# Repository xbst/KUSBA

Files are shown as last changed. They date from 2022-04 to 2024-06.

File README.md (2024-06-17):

# Klipper USB Accelerometer
A PCB designed to make [Klipper's](https://github.com/KevinOConnor/klipper) [input shaping](https://github.com/Klipper3d/klipper/blob/master/docs/Resonance_Compensation.md) much easier by simplifying the wiring and config for [measuring resonances](https://github.com/KevinOConnor/klipper/blob/master/docs/Measuring_Resonances.md). You just need this PCB and a USB C cable.
<br>

## Purchasing a KUSBA
### United States
- [Amazon - Prime Shipping](https://www.amazon.com/Isiks-Tech-KUSBA-Klipper-Accelerometer/dp/B0C734JL4Z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)
- [Isik's Tech Store](https://store.isiks.tech/products/kusba-klipper-usb-accelerometer) (Me)
- [West3D](https://west3d.com/products/kusba-klipper-usb-accelerometer-by-isikstech)
- [XR Bunker](https://xrbunker.works/products/kusba-by-xbst_isik)
### Canada
- [Amazon - Ships from the US](https://www.amazon.ca/dp/B0C734JL4Z)
### United Kingdom
- [Printy Please](https://www.printyplease.uk/KUSBA)
### European Union
- [Lab4450 - Portugal](https://lab4450.com/product/ksuba-adxl345/)
### Australia
- [Unique Prints](https://uniqueprints.shop/shop/electronics-electrical/pcb/kusba-usb-adxl345-accelerometer-for-klipper/)
- [DREMC](https://store.dremc.com.au/products/kusba-usb-adxl345-accelerometer-for-klipper)
- [Orvil3D](https://orvil3d.com/products/kusba)

This project is licensed under [GPL v3](./LICENSE), meaning vendors are allowed to sell KUSBA PCBs without paying me. If you'd like to support the development of this and future projects please consider [sponsoring](https://github.com/sponsors/xbst) me on GitHub. You can also subscribe on [Patreon](https://l.isiks.tech/patreon) or [YouTube](https://l.isiks.tech/member).

You can also use the included gerber files to order your own from a PCB manufacturer like [PCBWay](https://www.pcbway.com/setinvite.aspx?inviteid=374841) or [JLCPCB](https://jlcpcb.com/).
<br>

## Instructions
[KUSBA Instructions](./Docs/v2-Rampon-Firmware.md)

## Toolhead Mounts

Toolhead mounts can be found [here](./Mounts).
<br>The CAD model of the PCB and some toolhead mounts can be found [here](./CAD).
<br> 

## Versions

| Parts | KUSBA v2 | KUSBA v1 |
| --- | --- | ---|
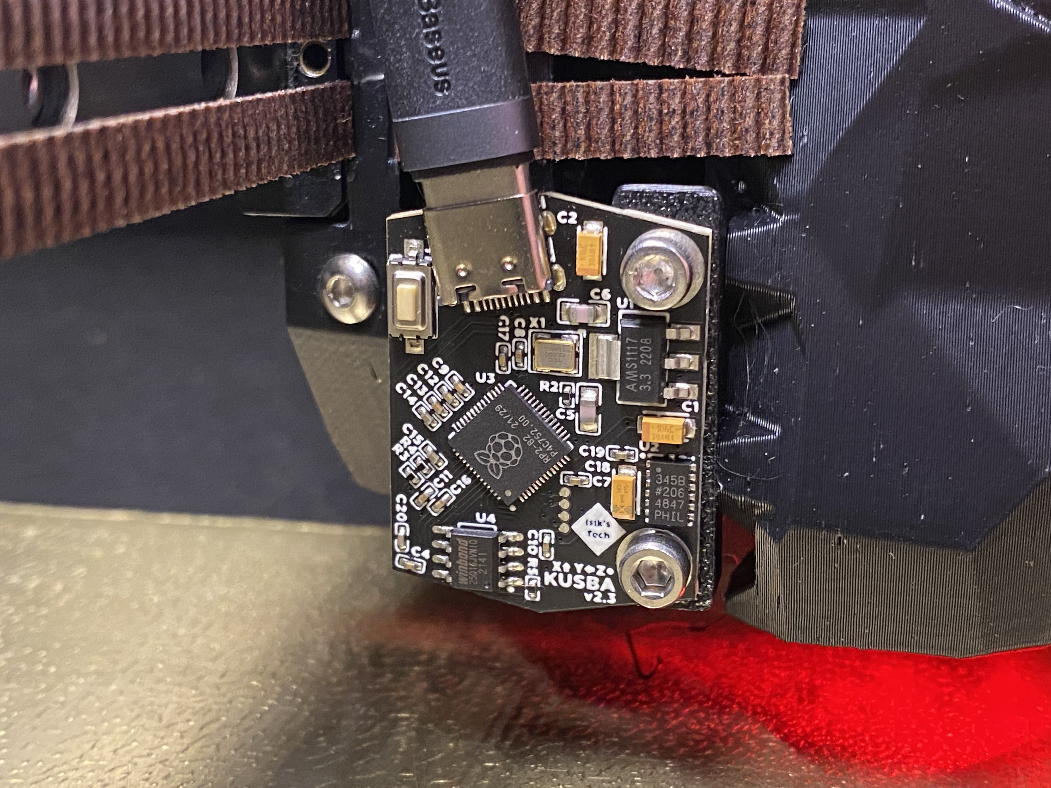
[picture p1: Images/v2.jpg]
v2.3
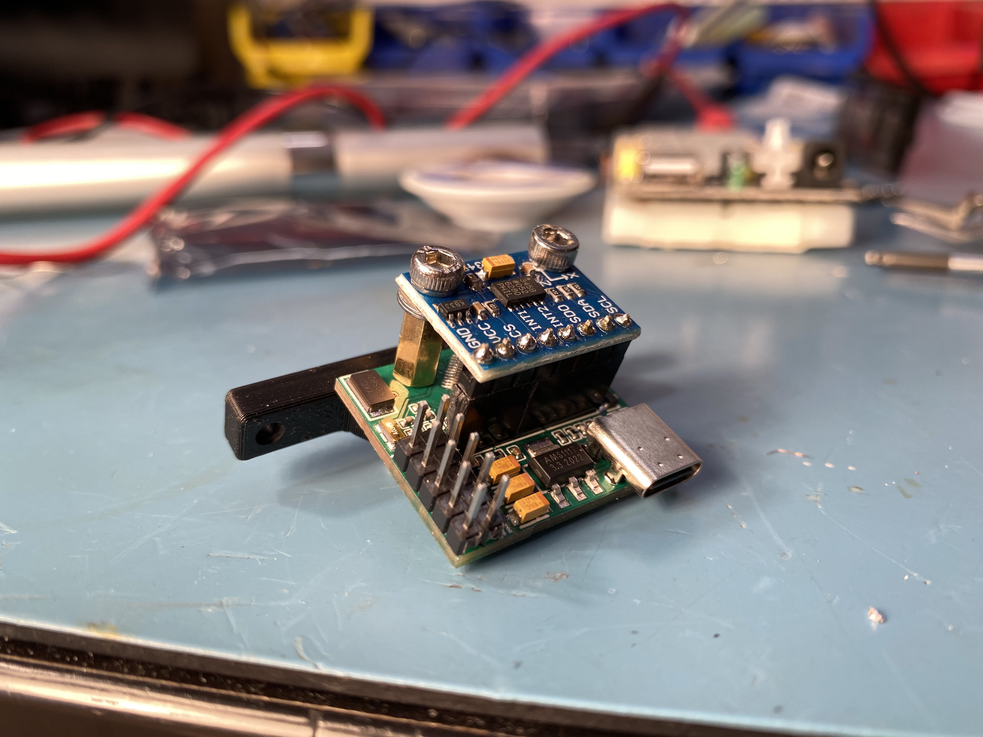
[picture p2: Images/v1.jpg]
v1.0
| Picture |  |  |
| YouTube Video | [YouTube Video](https://www.youtube.com/watch?v=gtrQXdAaXB4) | [YouTube Video](https://www.youtube.com/watch?v=tDQd-jGegX0) |
| MCU | RP2040 | STM32F103 |
| Accelerometer | ADXL345BCCZ-RL7 | External ADXL345 Module |
| 3.3V Regulator | AMS1117-3.3 | AMS1117-3.3 |
| Flash | W25Q16JVSNIQ | N/A |
| Connector | USB C | [USB C](https://www.digikey.com/en/products/detail/gct/USB4085-GF-A/9859733) |
| Smallest SMT | 0402 | 0402 |
| Other Parts Needed | USB C Cable, M3 Screws | ADXL345 Module, USB C Cable, M3 Screws, UART Programmer |
| Dimensions | 34.0 x 25.0 mm | 25.0 x 30.0 mm |

TL;DR: v2 is better

## YouTube

I am a YouTube content creator. If you want content about these projects & more, please consider [subscribing to my YouTube channel](https://www.youtube.com/channel/UClAWYmCkHjsbaX9Wz1df2mg).
<br>

If you feel like contributing to the development of this project and other projects like this you can sponsor me on [GitHub](https://github.com/sponsors/xbst), subscribe on [Patreon](https://l.isiks.tech/patreon) or [YouTube](https://l.isiks.tech/member).

## Notes
- Readme files in this repo contain Amazon Associate, Aliexpress affiliate, PCBWay affiliate links. I make a comission on qualifying purchases.
- This project does not come with any warranty, if you choose to build/use a KUSBA, you are doing this at your own risk!
- If you want to sell KUSBA PCBs, you are allowed to, and you will not owe me any royalties. **You cannot claim that I endorse the sale**. You can check the license file for more information. However, if you **wish** to give me a share you can sponsor me on [GitHub](https://github.com/sponsors/xbst), subscribe on [Patreon](https://l.isiks.tech/patreon) or [YouTube](https://l.isiks.tech/member).

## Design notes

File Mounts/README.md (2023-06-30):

# Mounts
|Name|Toolhead|KUSBA Version|Notes|By|
|---|---|---|---|---|
|[StealthBurner Mount](./StealthBurner.stl)|Voron StealthBurner|v2.3 & v2.4|Limits X travel very slightly (negligible)|xbst_|
|[StealthBurner Cover](./SB_cover.stl)|Voron StealthBurner|v2.3 & v2.4|Optional cover, further limits X travel but only a few mm|Samwiseg0|
|[AfterBurner Mount](./AfterBurner.stl)|Voron AfterBurner|v2.3 & v2.4|UNTESTED but should work. Front mount.|xbst_|
|[Mini-SB Front Mount](./MiniSB_Front.stl)|Voron Mini-StealthBurner|v2.3 & v2.4|Easiest mount to attach/remove. Very similar to the Mini-AB mount|xbst_|
|[Mini-SB Rear Mount](./MiniSB_Patrick.stl)|Voron Mini-StealthBurner|v2.3 & v2.4|If you prefer accelerometers near the carriage use this one. Alternate strain relief with the KUSBA mount. Not compatible with toolhead PCBs|xbst_|
|[Mini-AB Front Mount](./MiniAB.stl)|Voron Mini-AfterBurner|v2.3 & v2.4|Mounts the KUSBA in front of the toolhead, replace the 2 long M3 screws|xbst_|
|[Mini-AB Cover](./MiniAB_Cover.stl)|Voron Mini-AfterBurner|v2.3 & v2.4|Optional cover|Samwiseg0|
|[M6 KUSBA Nozzle Mount](./M6_KUSBA_Mount.stl)|M6 Nozzle Mount|v2.3 & v2.4|Cover recommended so Tap homing can be used. Requires M6 SHCS/BHCS 10mm screw, remove nozzle. Add "axes_map: y, x, z" to [adxl345] section config for proper orientation with the USB-C facing forward. |GiulianoM|
|[Dragon Burner Mount](./Dragon_Burner_Rigonzalez6.stl)|Dragon Burner|v2.3 & v2.4||rigonzalez6|
|[MicroSwiss NG Mount](./MicroSwiss_NG.stl)|MicroSwiss NG Direct Drive|v2.3 & v2.4|It uses inserted M3 nuts to mount the KUSBA board and fix it to the extruder backplate. [Print details](https://www.printables.com/model/516393-kusba-mount-for-micro-swiss-ng-extruder) |luisillo26|

<br>**Feel free to contribute more mounts. Either create a PR or DM me on Discord to contribute.**
<br>**KUSBA v1.0 users can use the standard ADXL345 mounts. The mount holes are the same as the GY ADXL345 module, size might be a problem.**

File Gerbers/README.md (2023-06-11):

# HW Changelog

|Version|Notes|Files|
|---|---|---|
|v1.0|Read the main [Readme](../README.md#version-10) file for more information.|[Gerbers](./Old-Versions/v1.0)|
|v2.0|More info about v2 vs v1 is on the main [Readme](../README.md).|Not Released (HW Bugs)|
|v2.1| Fixed the v2.0 communication problems.|Not Released (HW Bugs)|
||Many components are relocated.||
||LED is removed because it was unnecessary.||
||PCB is smaller now (35.6mmx25mm).||
|v2.2|Made the PCB slightly larger (36.4mmx25mm) to allow the use of M3 screws. |Not Released (Untested)|
||Made some test pads larger.||
|v2.3|Fixed a HW bug that affects about 20% of PCBs (or less based on another person ordering v2.1).|[Gerbers](./Old-Versions/v2.3)|
||PCB is even smaller (34mmx25mm) while still using M3 screws.||
|v2.4|Adds USB C-to-C cable support.|[Gerbers](./Latest-Tested-Version)|
||Minor silkscreen and other cosmetic changes.||
||Same size and layout. Compatible with v2.3 mounts.||

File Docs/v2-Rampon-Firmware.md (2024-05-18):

### 0. Klipper Prep
Taken from the [official Klipper docs](https://www.klipper3d.org/Measuring_Resonances.html#software-installation).
1. Run the following commands in order. This will take some time.
```
~/klippy-env/bin/pip install -v numpy
sudo apt update
sudo apt install python3-numpy python3-matplotlib libatlas-base-dev libopenblas-dev
```

### :warning: Seeing "MCU Protocol Error"?
Klipper devs did some major changes to the ADXL code, and as a result older Rampon is not compatible with newer Klipper versions, and vice-versa.
If your Klipper version is v0.12.0-85 or later, use Rampon v0.4. If it is before this update, use Rampon v0.3. If your KUSBA stopped working after a Klipper update, you need v0.4.

|Klipper Pre-"Bulk Sensor" Update|Klipper Post-"Bulk Sensor" Update|
|---|---|
|[v0.3](https://github.com/rogerlz/rampon_anchor/releases/download/v0.3.0/rampon_anchor_kusba.uf2)|[v0.4](https://github.com/rogerlz/rampon_anchor/releases/download/v0.4.0/rampon_anchor_kusba.uf2)|

Follow these steps to flash firmware:

### 1. Flash Rampon Anchor to the MCU

You can do this step on a PC or on your Raspberry Pi (or another Linux machine).
<br> Your KUSBA might already have the firmware pre-flashed. If it does, you can skip this step.
<details>
  <summary>PC (Easier)</summary>

1. Download the Rampon Anchor Firmware from its [GitHub repo](https://github.com/rogerlz/rampon_anchor).

|Klipper Pre-"Bulk Sensor" Update|Klipper Post-"Bulk Sensor" Update|
|---|---|
|[v0.3](https://github.com/rogerlz/rampon_anchor/releases/download/v0.3.0/rampon_anchor_kusba.uf2)|[v0.4](https://github.com/rogerlz/rampon_anchor/releases/download/v0.4.0/rampon_anchor_kusba.uf2)|

2. Connect the KUSBA to your PC while holding down the button on the KUSBA. A new drive will be connected, open if it isn't opened automatically.
3. Drag & drop the downloaded .UF2 file. KUSBA will disconnect and the window will close on its own. Your KUSBA is ready.
</details>
<details>
  <summary>Raspberry Pi (Linux CLI)</summary>

  1. Connect the KUSBA to your Raspbery Pi while holding down the button on the KUSBA.
  2. SSH into your Raspberry Pi.
  3. Download the Rampon Anchor Firmware from its [GitHub repo](https://github.com/rogerlz/rampon_anchor).
  ```
  sudo wget https://github.com/rogerlz/rampon_anchor/releases/download/v0.4.0/rampon_anchor_kusba.uf2
  ```
  4. Find the storage location of the KUSBA. This will usually be sda1. Use this command one time with the KUSBA unplugged and one time with KUSBA plugged in (while holding down the button on the KUSBA) to verify. `ls /dev/`
  5. Flash the firmware.
  ```
  sudo mount /dev/sda1 /mnt
  sudo cp rampon_anchor_kusba.uf2 /mnt
  sudo umount /mnt
  ```
</details>

### 2. Configure Klipper
1. Download the [adxlmcu.cfg](../Firmware/v2-Rampon/adxlmcu.cfg) file from this repo and add it to your Klipper config directory.
4. Edit the adxlmcu.cfg file. Change the the probe points.
5. Add the following to your printer.cfg:
```
[include adxlmcu.cfg]
```
4. Do your testing. When done comment the include line to disable the KUSBA. (If you don't do this and unplug the KUSBA, Klipper won't work.)
```
# [include adxlmcu.cfg]
```

<details>
  <summary>LEGACY INSTRUCTIONS</summary>
  
  Ignore unless you know you need these instructions.
  
  [KUSBA v2 Non-Rampon Klipper Instructions](./v2-Firmware.md) - NOT RECOMMENDED
  
  [KUSBA v1 Instructions](./v1-Firmware.md)
  
</details>

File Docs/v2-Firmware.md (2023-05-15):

### 0. Klipper Prep
Taken from the [official Klipper docs](https://www.klipper3d.org/Measuring_Resonances.html#software-installation).
1. Run the following commands in order. This will take some time.
```
~/klippy-env/bin/pip install -v numpy
sudo apt update
sudo apt install python3-numpy python3-matplotlib libatlas-base-dev
```

### 1. Flash Klipper to the MCU
1. Connect the KUSBA to your Raspbery Pi while holding down the button on the KUSBA.
2. SSH into your Raspberry Pi.
3. Go to the Klipper directory
```
cd klipper
```
4. Clean remaining files from previous build.
```
make clean
```
5. Choose the options for the build.
```
make menuconfig
```
Use the following settings:
```
Micro-controller Architecture: Raspberry Pi RP2040
Communication inferface: USB
```
6. Build the firmware
```
make
```
7. Find the storage location of the KUSBA. This will usually be sda1. Use this command one time with the KUSBA unplugged and one time with KUSBA plugged in (while holding down the button on the KUSBA) to verify.
```
ls /dev/
```
8. Flash the firmware.
```
sudo mount /dev/sda1 /mnt
sudo cp out/klipper.uf2 /mnt
sudo umount /mnt
```

### 2. Configure Klipper
1. Go back to the home directory.
```
cd ~
```
2. Download the [adxlmcu.cfg](../Firmware/v2/adxlmcu.cfg) file from this repo and add it to your Klipper config directory.
3. Find your MCU address.
```
ls /dev/serial/by-id/*
```
4. Edit the adxlmcu.cfg file. Change the MCU serial address and the probe points.
5. Add the following to your printer.cfg:
```
[include adxlmcu.cfg]
```
6. Do your testing. When done comment the include line to disable the KUSBA. (If you don't do this and unplug the KUSBA, Klipper won't work.)
```
# [include adxlmcu.cfg]
```

<br>

### NOTE: The first reading from the accelerometer will be invalid (usually f2 vs e5). This is expected and your KUSBA will still work fine after the first query. Run ``ACCELEROMETER_QUERY`` once before starting measuring resonances.

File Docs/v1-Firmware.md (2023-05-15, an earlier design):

**Warning: Make sure to use plastic washers between metal screws and PCB!**

### 0. Klipper Prep
Taken from the [official Klipper docs](https://www.klipper3d.org/Measuring_Resonances.html#software-installation).
1. Run the following commands in order. This will take some time.
```
~/klippy-env/bin/pip install -v numpy
sudo apt update
sudo apt install python3-numpy python3-matplotlib libatlas-base-dev
```
### 1. Flash the Bootloader
You will need a USB UART programmer. I recommend using a CP2012 programmer, because it is cheap, easy to source, and it works.
Programmer:
[Aliexpress](https://s.click.aliexpress.com/e/_AB7gkA)
[Amazon](https://amzn.to/2OTzpI8)

You will also need some Female/Female dupont cables:
[Aliexpress](https://s.click.aliexpress.com/e/_9GgrhS)
[Amazon](https://amzn.to/3uAZU5E)

1. Download & install the [CP2012 drivers](https://www.silabs.com/developers/usb-to-uart-bridge-vcp-drivers). (on your Windows PC)
2. Download & install the [flasher](https://www.st.com/en/development-tools/flasher-stm32.html). (on your Windows PC)
3. Download the [STM32duino bootloader](https://github.com/rogerclarkmelbourne/STM32duino-bootloader/blob/master/binaries/maple_mini_boot20.bin). (on your Windows PC)
4. Jump the boot pins:
<br>BOOT0 > VCC
<br>BOOT1 > GND
5. Connect power from UART programmer:
<br>3V3 > VCC
<br>GND > GND
6. Connect the UART pins:
<br>TX > RX1
<br>RX > TX1
7. Plug in the UART programmer to your Windows PC.
8. Launch the Demonstratior GUI (STM32 Flasher Software).
9. Choose the correct COM port, hit next, and next again.
10. Make sure the chip detected in this step is correct, hit next again.
11. Choose "Download to device", click "..." to select the bin file. You will need to change the file type from .s19 to .bin in the dialog. Check "Verify after download", and hit next.
12. The bootloader will now be flashed. One it is complete you can exit the program. Unplug the programmer, and remove all wires and jumpers from the PCB.

### 2. Flash Klipper to the MCU
1. Connect the KUSBA to your Raspbery Pi. The LED on the PCB should be flashing.
2. SSH into your Raspberry Pi.
3. Go to the Klipper directory
```
cd klipper
```
4. Clean remaining files from previous build.
```
make clean
```
5. Choose the options for the build.
```
make menuconfig
```
Use the following settings:
```
Micro-controller Architecture: STMicroelectronics STM32
Processor Model: STM32F103
Bootloader Offset: 8KiB Bootloader (stm32duino)
```
6. Build the firmware
```
make
```
7. Verify that the MCU is connected. There should be a "1eaf:0003" device connected. 
```
lsusb
```
If there is no "1eaf:0003" but there is a "1eaf:0004":
<br>
Sometimes the bootloader runs for only a short period after boot (if it thinks there is already a program, so it boots to it). If you unplug & replug in the mcu, and run the "lsusb" quickly enough, you will see a "1eaf:0003". If this is the case, you will need to time the next step well.

8. Flash the firmware.
```
dfu-util -d 1eaf:0003 -a 2 -R -D out/klipper.bin
```
9. Reset or unplug and replug in the MCU.

### 3. Configure Klipper
1. Go back to the home directory.
```
cd ~
```
2. Download the [adxlmcu.cfg](../Firmware/v1/adxlmcu.cfg) file from this repo and add it to your Klipper config directory.
3. Find your MCU address.
```
ls /dev/serial/by-id/*
```
4. Edit the adxlmcu.cfg file. Change the MCU serial address and the probe points.
5. Add the following to your printer.cfg:
```
[include adxlmcu.cfg]
```
6. Do your testing. When done comment the include line to disable the KUSBA. (If you don't do this and unplug the KUSBA, Klipper won't work.)
```
# [include adxlmcu.cfg]
```

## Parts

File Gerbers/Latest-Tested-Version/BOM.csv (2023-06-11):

ID | Name | Designator | Footprint | Quantity | Manufacturer Part | Manufacturer | Supplier | Supplier Part | Price
1 | 12MHz | X1 | OSC-SMD_4P-L3.2-W2.5-BL | 1 | X322512MSB4SI | YXC | LCSC | C9002 | 0.014
2 | USB3.1C16PFSMT | USBC2 | USB-C-SMD_TYPE-C-USB-17 | 1 | - | LCSC | LCSC | C167321 | 0.059
3 | RP2040 | U3 | LQFN-56_L7.0-W7.0-P0.4-EP | 1 | RP2040 | Raspberry Pi(树莓派) | LCSC | C2040 | 0.174
4 | ADXL345BCCZ-RL7 | U2 | LGA-14_L5.0-W3.0-P0.80-BL | 1 | ADXL345BCCZ-RL7 | ADI | LCSC | C9667 | 0.269
5 | AMS1117-3.3 | U1 | SOT-223-3_L6.5-W3.4-P2.30-LS7.0-BR | 1 | AMS1117-3.3 | AMS | LCSC | C6186 | 0.024
6 | K2-3.6×6.1_SMD | BOOTSEL1 | KEY-SMD_2P-L6.2-W3.6-LS8.0 | 1 | K2-1107ST-A4SW-06 |  | LCSC | C118141 | 0.011
7 | 10u | C1,C3 | CAP-SMD_L3.2-W1.6-R-RD | 2 | TAJA106K016RNJ | AVX | LCSC | C7171 | 0.014
8 | 1u | C18 | CAP-SMD_L3.2-W1.6-R-RD | 1 |  |  | LCSC | C141744 | 0.011
9 | W25Q16JVSNIQ | U4 | SOIC-8_L4.9-W3.9-P1.27-LS6.0-BL | 1 | W25Q16JVSNIQ | Winbond Elec | LCSC | C115407 | 0.062
10 | 1K 1% | R5 | R0402 | 1 |  |  | LCSC | C11702
11 | 27R4 1% | R4,R3 | R0402 | 2 |  |  | LCSC | C31439
12 | 2u2 | C20 | C0402 | 1 |  |  | LCSC | C12530
13 | 100n | C17,C16,C13,C12,C11,C10,C9,C8,C7,C4,C19 | C0402 | 11 |  |  | LCSC | C1525
14 | 1u | C15,C14 | C0402 | 2 |  |  | LCSC | C52923 | 0.001
15 | 470R 1% | R2 | R0402 | 1 |  |  | LCSC | C25117
16 | 27p | C6,C5 | C0603 | 2 |  |  | LCSC | C107045
17 | 5K1 1% | R6,R7 | R0402 | 2 |  |  | LCSC | C328327 | 0.001

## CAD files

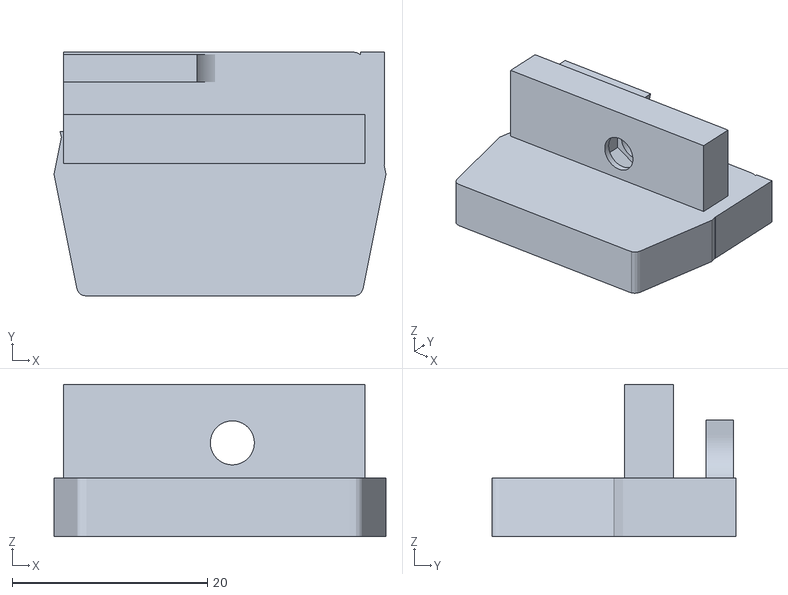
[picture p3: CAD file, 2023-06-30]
Mounts/MicroSwiss_NG.stl
34.0 x 25.0 x 15.6

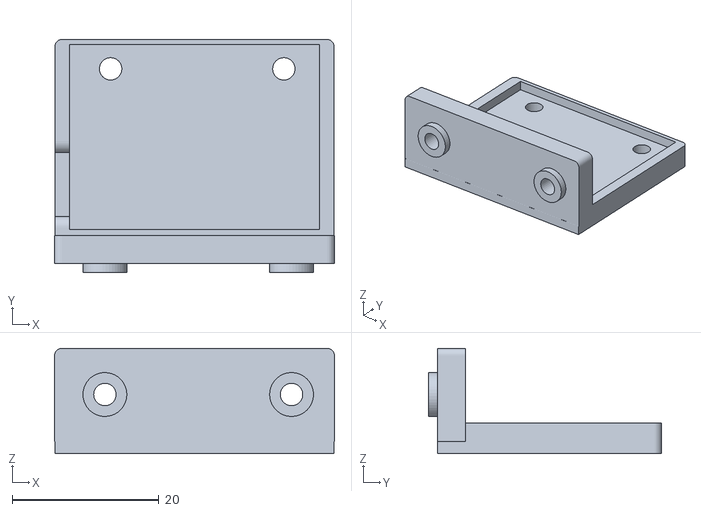
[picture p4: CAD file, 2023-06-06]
Mounts/Dragon_Burner_Rigonzalez6.stl
38.1 x 31.8 x 14.3

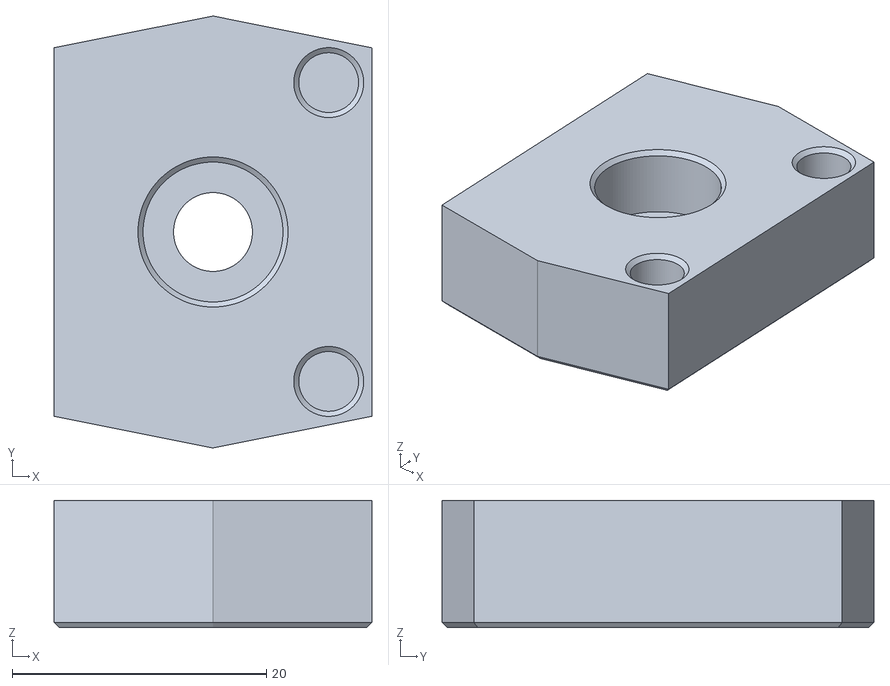
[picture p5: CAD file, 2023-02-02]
Mounts/M6_KUSBA_Mount.stl
25.0 x 34.0 x 10.0

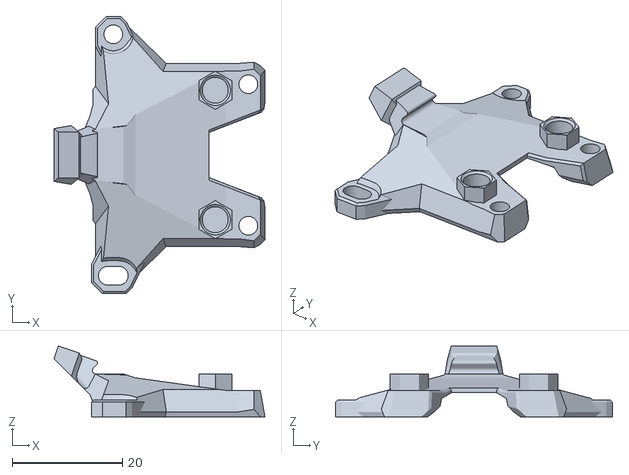
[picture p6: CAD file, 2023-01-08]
Mounts/MiniSB_Patrick.stl
38.3 x 50.3 x 12.9

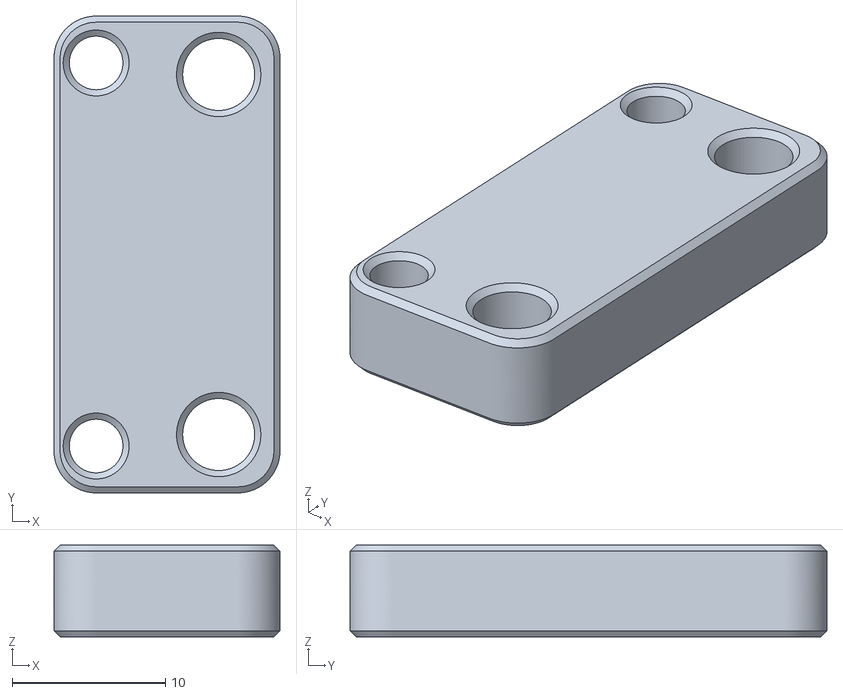
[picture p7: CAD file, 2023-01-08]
Mounts/MiniSB_Front.stl
14.8 x 31.1 x 6.00

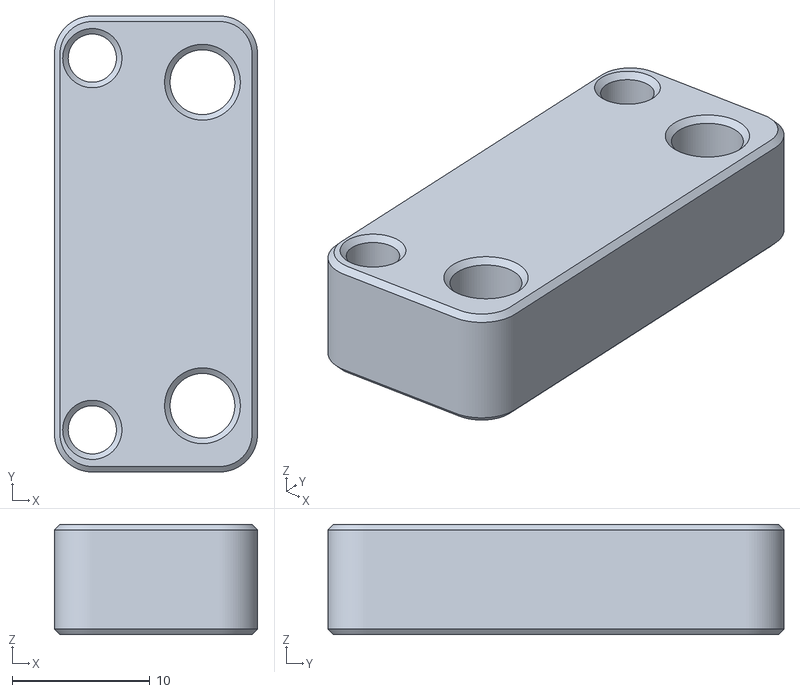
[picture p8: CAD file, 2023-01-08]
Mounts/MiniAB.stl
14.8 x 33.1 x 8.00

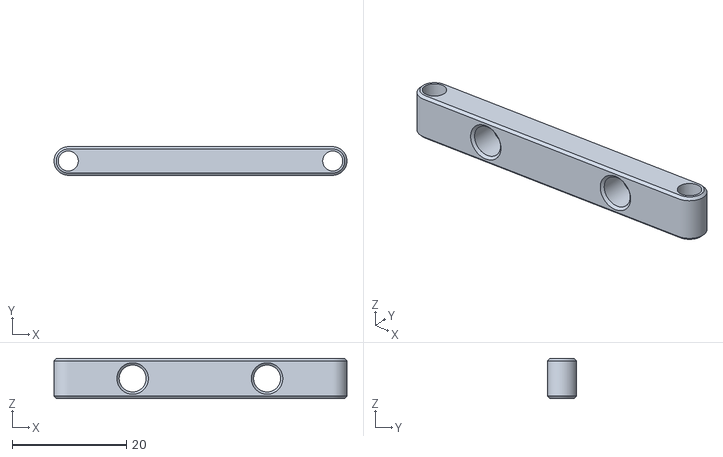
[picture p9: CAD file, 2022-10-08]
Mounts/AfterBurner.stl
51.2 x 5.00 x 7.00

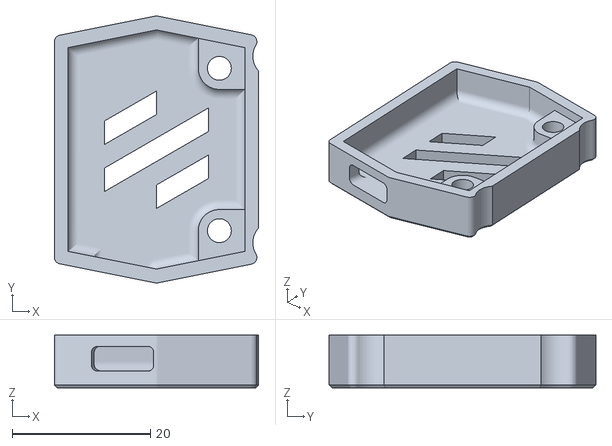
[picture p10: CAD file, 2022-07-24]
Mounts/MiniAB_Cover.stl
29.6 x 38.7 x 7.60

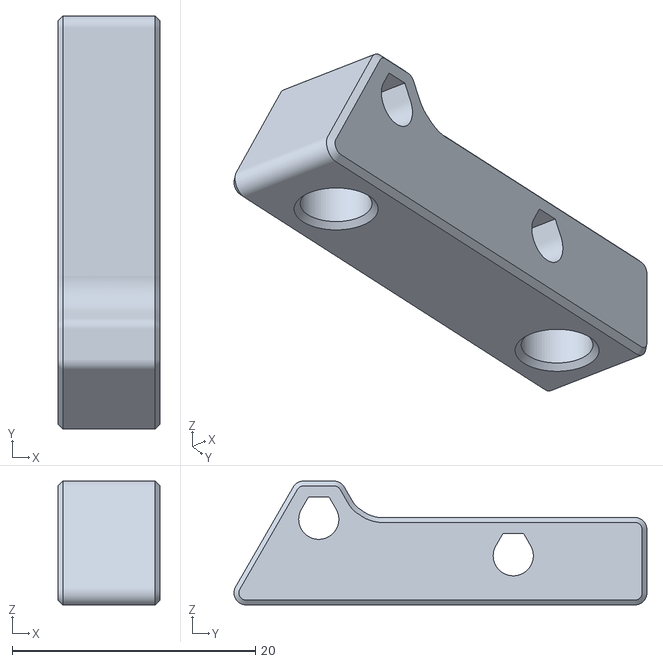
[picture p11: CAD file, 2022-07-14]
Mounts/StealthBurner.stl
8.40 x 34.0 x 10.2

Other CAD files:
Mounts/SB_cover.stl

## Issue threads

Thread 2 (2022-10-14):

Perhaps dumb question - will this work with a laptop running Ubuntu?

wiilover22, 2022-10-14:
This is probably a really stupid question - but since RPI's are so scarce right now, I'm running Klipper on an old laptop of mine sitting next to my 3D printer.

Which is why I went looking for USB connection ADXL345's.

If I already have Klipper installed on the Laptop, and my 3D printer flashed with the Klipper firmware - if I buy this USB ADXL345, is it just plug, config, and play? Does anything need to change? Thanks! Would love to buy one if it works with my laptop >.<

xbst, 2022-10-14:
It should work work fine, it's the same software. One thing to keep in mind is KUSBA is not compatible with USB C to C cables, so you need a USB A port on your laptop.

wiilover22, 2022-10-14:
So since I have everything installed already, it's just plug - setup the config file to read from the USB port - and run the resonance tests? Or do I have to recompile Klipper for my laptop or printer...or something?

Also...I have a bed slinger printer...does that mean I have to buy 2 of these so I can read the resonances from both the bed and printer head - if you happen to know...?

xbst, 2022-10-15:
You can just follow the instructions on this repo. I'm not sure where the wget command will download the cfg so you might have to manually move it. Other than that it should be the same.
You can buy just 1 and move the accelerometer, but if you want to measure both with 1 command or if you don't want to move it you will need 2.

wiilover22, 2022-10-15:
Thanks for the help!

Closed 2022-10-15.

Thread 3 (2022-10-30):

KUSBA with standard parts

Ritterbrater, 2022-10-30:
Hi,
nice project!
Instead of using a custom PCB I would like to take "standard" parts.
Is it possible to take a regular Raspberry Pi Pico Board with a ADXL345 module board? Do I only need to connect the pins GPIO0 - GPIO4 and then flash your firmware?

Another question: Are there any limitiations for the frequency measurement due to protocol change SPI <-> USB?

Thank you.

xbst, 2022-10-31:
It's possible. There are a few guides for that on the internet, I think Nero3D has a good video on that topic.

The protocol between the accelerometer and the MCU is still SPI, performance should be the same.

Ritterbrater, 2022-10-31:
Ah, ok, I see. E.g.: https://www.youtube.com/watch?v=W_VHbT_tsZw
Thank you for the explanations.

Closed 2022-10-31.

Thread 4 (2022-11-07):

documentation of the protocol

tcurdt, 2022-11-07:
Fantastic project.
I was thinking of building something similar for another context (non-Klipper).

I am trying to understand how the communication works over USB.
What's the protocol? Are there some docs?
Is the latency a problem for the measurements?

Where is the code that actually runs on the MCU?
And what's the flash used for?

xbst, 2022-11-07:
The protocol is spi to the rp2040, then usb, so no different from the normal klipper setup. Latency shouldn't be any different compared to wiring the spi pins to a normal controller or a pi pico. The code is klipper, built at the time of flashing with the latest files available at the time.  flash is used to store the klipper code.

tcurdt, 2022-11-07:
> The protocol is spi to the rp2040

of course

> then usb

And that's the bit I am after.
But it sounds like this might be more of a question for the Klipper project.

To give more context:
Let's say I connect board and connect it to linux machine.
How could I talk to the board (without using Klipper)?

Seems I would need a custom firmware for the rp2040 and something on the host as well.

xbst, 2022-11-08:
Probably something can be programmed for that with arduino IDE.

Closed 2022-11-12.

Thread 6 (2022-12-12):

`Invalid adxl345 id (got f2 vs e5)` error running `ACCELEROMETER_QUERY` for the first time

hakimio, 2022-12-12:
I understand that `Invalid adxl345 id (got f2 vs e5)` error is documented but instead of ignoring it, it should be fixed. This doesn't happen with `FYSETC Portable Input Shaper` and should not happen with `KUSBA`.

xbst, 2022-12-13:
This happens with a Raspberry Pi Pico with ADXL345 too, not just KUSBA. This is a Klipper problem and there is nothing I can do to fix it.

hakimio, 2022-12-13:
- Why doesn't this happen with `FYSETC Portable Input Shaper` which also uses `RP2040`?
- If it's Klipper bug, where is the bug report and, if you know what's causing the issue, why don't you create a PR for Klipper?

hakimio, 2022-12-13:
I guess you were referring to this closed bug report: https://github.com/Klipper3d/klipper/issues/4712

xbst, 2022-12-13:
I have no idea why FYSETC PIS doesn't have this problem. Me and other people (simple discord searches can find some recent examples) had the invalid ID issue on the first query with Pi Picos too, not just KUSBA. This indicates a software issue.

One difference between the KUSBA vs PIS is, PIS uses different GPIO pins for the SPI bus to the ADXL, could be related. But the pins the KUSBA use are full HW SPI pins too, and they should work the same. Again, the only possible explanation I can think of for this is a Klipper bug, even if it is not reported on GitHub.

hakimio, 2022-12-13:
Can you create a bug report on Klipper repo and link it here?

Fragmon, 2023-01-04:
Hey, i try to create a macro that use the query for the test. But klipper dont stop the execution between the macros. Do you know a solution?

   ACCELEROMETER_QUERY
   G4 P10000
   TEST_RESONANCES AXIS=X

Fragmon, 2023-01-04:
I found a solution:

Use this:
[adxl345]
cs_pin: adxl:gpio1
#spi_bus: spi0a
spi_software_sclk_pin: adxl:gpio2
spi_software_mosi_pin: adxl:gpio3
spi_software_miso_pin: adxl:gpio0

xbst, 2023-01-12:
Ideally I prefer hardware SPI over software SPI, but I'll test it and if this fixes the issue without producing worse results I'll add it as an option to the .cfg.

Witawat, 2023-02-24:
Invalid adxl345 id (got f2 vs e5).
This is generally indicative of connection problems
(e.g. faulty wiring) or a faulty adxl345 chip.

how to fix ?
or use klipper version ?

xbst, 2023-02-24:
It is covered in the instructions: https://github.com/xbst/KUSBA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
First reading will be invalid, should work fine after that.

Closed 2023-02-02.

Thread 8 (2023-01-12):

Issues reconnecting the MCU

housam-s, 2023-01-12:
After setting up the KASUBA ADXL and following the steps below, i got it to work perfectly the first time.
However, upon unplugging it and putting it away for a while, I wasnt able to get it going again easily. I am finding myself having to run through all the steps again before it will randomly decide to show up as an MCU USB device.
Seems like a bit of work to get it going again after unplugging it. Is this the way it is supposed to be or am I missing something?

EDIT: User error, have additional USB devices plugged in which have changed the port ID they are connected to.

Closed 2023-01-12.

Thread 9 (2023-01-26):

Unknown spi_bus 'spi0a'

mmithoefer, 2023-01-26:
I flashed my KUSBA and adjusted my serial address to : `serial: /dev/serial/by-id/usb-Klipper_rp2040_E661347507974224-if00` which i determined by using `ls /dev/serial/by-id/*`.
When i try to start klipper i get  the following error:

`Unknown spi_bus 'spi0a'`

when I uncomment the [include adxlmcu.cfg] and add
```
[mcu adxl]
serial: /dev/serial/by-id/usb-Klipper_rp2040_E661347507974224-if00
```
to my printer.cfg it starts just fine and the mcu adxl shows up in mainsail on the config tab

xbst, 2023-01-29:
You don't add the mcu to the printer.cfg, the mcu is in the adxlmcu.cfg. You just need to change the address in that file.

mmithoefer, 2023-01-29:
I´m aware of that. I did that only as a trouble-shooting measure. Whenever
 `[adxl345]
cs_pin: adxl:gpio1
spi_bus: spi0a`
is uncommented i get the described error

xbst, 2023-01-30:
That is weird. Can you update klipper? It sounds like a software issue since spi0a is a bus defined in the Klipper code for the RP2040.

mmithoefer, 2023-01-30:
I just did. Same error unfortunately

xbst, 2023-02-01:
Can you attach your printer.cfg and all .cfg files included with [include]?

mmithoefer, 2023-02-01:
Found the problem. Mistake on my part. I had a adxl section in my printer.cfg from previous experiments with other accelerometers.

Closed 2023-02-01.

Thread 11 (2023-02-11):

2.3 board loses flash if disconnected

cyborgcnc, 2023-02-11:
I have a 2.3 board, and it works as it should when flashed, however, if I disconnect the board, the flash file is no longer there....I have to go through the steps of mounting the file system again, and re-flashing, and then it works again...I thought this was supposed to be fixed in 2.3, but I am finding it is still there....wondering if I am doing something wrong?  Accelerometer works as it should once flashed, Klipper sees it etc.

xbst, 2023-02-11:
This is a known issue even with v2.3 but only affects about 1-2% of the PCBs according to data I get from vendors. Most of these are caught by the vendor before shipping to the customer but sometimes a faulty one is accidentally shipped. It sounds like you might have one of these PCBs unfortunately. Try contacting the seller.

cyborgcnc, 2023-02-11:
OK, I will do that...in the mean time, I guess I will keep re-flashing it for when I want to use it....royal  pain in the you know what....Thanks for your response!

pellcorp, 2023-11-09:
I have this exact issue with the 2.4 board as well :-(

Closed 2023-02-11.

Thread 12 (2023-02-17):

Trouble with make menuconfig

jperquin, 2023-02-17:
Have Fluiddpi / Moonraker Klipper installed on a Rpi 3b (BCM2835) and has been running fine with my Creality Ender6 that has been Klipper-ized with a custom flavour (https://3dprintbeginner.com/how-to-install-klipper-on-creality-ender-6/)

The KUSBA 2.3 is supposed to come pre-flashed with Klipper but does not show up under ls /dev/serial/by-id/*. The Ender6 does however (/dev/serial/by-id/usb-1a86_USB_Serial-if00-port0).

So figured I need to (re)flash the KUSBA, but following the instructions, I am running into an issue with make menuconfig.

I am supposed to be able to select these options:
```
Micro-controller Architecture: Raspberry Pi RP2040
Communication inferface: USB
```
But I am getting this of options for Micro-controller Architecture:

```
( ) Atmega AVR
( ) SAM3/SAM4 (Due and Duet)
( ) SAMD21/SAMD51
( ) LPC176x (Smoothieboard)
( ) STMicroelectronics STM32
( ) Beaglebone PRU
(X) Linux process
( ) Host simulator
```
So no "Raspberry Pi RP2040"..

Not sure how to proceed..

Your help is much appreciated.
Rgds, JP

xbst, 2023-02-17:
When did you last update Klipper? RP2040 is a newer chip than those so you might be running a really outdated version, from before RP2040 support. Try updating Klipper.

xbst, 2023-03-02:
Solved in another issue.

Closed 2023-03-02.

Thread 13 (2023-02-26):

KUSBA not recognized on USB

DK4FT, 2023-02-26:
received my KUSBA from lab4450.com a while ago and try to include it in my system now without success.

When pluggin in(with button pressed) the device is not recognized as a drive on my RPi.
As lab4450 mention on their page, that their devices are pre-flashed with the klipper firmware I tested also without button pressed, but the KUSBA is not regognized.

Here snippets from the syslog on the klipper machine..

1. KUSBA just pluggged in:
```
Feb 26 09:19:06 klipper kernel: [321786.579968] usb 1-1.3: new full-speed USB device number 7 using xhci_hcd
Feb 26 09:19:07 klipper kernel: [321786.680213] usb 1-1.3: device descriptor read/64, error -32
Feb 26 09:19:07 klipper kernel: [321786.900097] usb 1-1.3: device descriptor read/64, error -32
Feb 26 09:19:07 klipper kernel: [321787.020502] usb 1-1-port3: attempt power cycle
Feb 26 09:19:08 klipper kernel: [321787.679929] usb 1-1.3: new full-speed USB device number 8 using xhci_hcd
Feb 26 09:19:08 klipper kernel: [321787.680199] usb 1-1.3: Device not responding to setup address.
Feb 26 09:19:08 klipper kernel: [321787.900078] usb 1-1.3: Device not responding to setup address.
Feb 26 09:19:08 klipper kernel: [321788.119873] usb 1-1.3: device not accepting address 8, error -71
Feb 26 09:19:08 klipper kernel: [321788.219886] usb 1-1.3: new full-speed USB device number 9 using xhci_hcd
Feb 26 09:19:08 klipper kernel: [321788.220172] usb 1-1.3: Device not responding to setup address.
```

2. Button pressed while pluggin in:
```
Feb 26 09:29:39 klipper kernel: [322419.318065] usb 1-1.3: new full-speed USB device number 10 using xhci_hcd
Feb 26 09:29:39 klipper kernel: [322419.418291] usb 1-1.3: device descriptor read/64, error -32
Feb 26 09:29:40 klipper kernel: [322419.638243] usb 1-1.3: device descriptor read/64, error -32
Feb 26 09:29:40 klipper kernel: [322419.858042] usb 1-1.3: new full-speed USB device number 11 using xhci_hcd
Feb 26 09:29:40 klipper kernel: [322419.958247] usb 1-1.3: device descriptor read/64, error -32
Feb 26 09:29:40 klipper kernel: [322420.178245] usb 1-1.3: device descriptor read/64, error -32
Feb 26 09:29:40 klipper kernel: [322420.298645] usb 1-1-port3: attempt power cycle
Feb 26 09:29:41 klipper kernel: [322420.968050] usb 1-1.3: new full-speed USB device number 12 using xhci_hcd
Feb 26 09:29:41 klipper kernel: [322420.968288] usb 1-1.3: Device not responding to setup address.
Feb 26 09:29:41 klipper kernel: [322421.188352] usb 1-1.3: Device not responding to setup address.
Feb 26 09:29:41 klipper kernel: [322421.408061] usb 1-1.3: device not accepting address 12, error -71
Feb 26 09:29:41 klipper kernel: [322421.508073] usb 1-1.3: new full-speed USB device number 13 using xhci_hcd
Feb 26 09:29:41 klipper kernel: [322421.508308] usb 1-1.3: Device not responding to setup address.
Feb 26 09:29:42 klipper kernel: [322421.728244] usb 1-1.3: Device not responding to setup address.
Feb 26 09:29:42 klipper kernel: [322421.948061] usb 1-1.3: device not accepting address 13, error -71
Feb 26 09:29:42 klipper kernel: [322421.948628] usb 1-1-port3: unable to enumerate USB device
Feb 26 09:29:53 klipper kernel: [322433.158187] usb 1-1.3: new full-speed USB device number 14 using xhci_hcd
Feb 26 09:29:53 klipper kernel: [322433.258356] usb 1-1.3: device descriptor read/64, error -32
Feb 26 09:29:53 klipper kernel: [322433.478410] usb 1-1.3: device descriptor read/64, error -32
Feb 26 09:29:54 klipper kernel: [322433.698219] usb 1-1.3: new full-speed USB device number 15 using xhci_hcd
Feb 26 09:29:54 klipper kernel: [322433.798392] usb 1-1.3: device descriptor read/64, error -32
Feb 26 09:29:54 klipper kernel: [322434.018417] usb 1-1.3: device descriptor read/64, error -32
Feb 26 09:29:54 klipper kernel: [322434.138656] usb 1-1-port3: attempt power cycle
Feb 26 09:29:55 klipper kernel: [322434.798216] usb 1-1.3: new full-speed USB device number 16 using xhci_hcd
Feb 26 09:29:55 klipper kernel: [322434.798449] usb 1-1.3: Device not responding to setup address.
Feb 26 09:29:55 klipper kernel: [322435.018475] usb 1-1.3: Device not responding to setup address.
Feb 26 09:29:55 klipper kernel: [322435.238283] usb 1-1.3: device not accepting address 16, error -71
Feb 26 09:29:55 klipper kernel: [322435.338247] usb 1-1.3: new full-speed USB device number 17 using xhci_hcd
Feb 26 09:29:55 klipper kernel: [322435.338476] usb 1-1.3: Device not responding to setup address.
Feb 26 09:29:55 klipper kernel: [322435.558444] usb 1-1.3: Device not responding to setup address.
Feb 26 09:29:56 klipper kernel: [322435.778234] usb 1-1.3: device not accepting address 17, error -71
Feb 26 09:29:56 klipper kernel: [322435.778773] usb 1-1-port3: unable to enumerate USB device
```

in both cases the device is not shown (as expected after these log messages.
```
pi@klipper:~ $ ls /dev/serial/by-id/*
/dev/serial/by-id/usb-1a86_USB2.0-Serial-if00-port0
```

Is there a chance to reacitvate the KUSBA, or is it a DOA case where I need to open a ticket with LAB4450?

xbst, 2023-02-26:
Did you try using a different USB A to C cable? Some cables only have the power wires and not the data wires. I'm not a Linux expert so I'm not a 100% sure if these errors would show up if a device is connected with a power-only cable. Also, C to C cables aren't supported. If a C to C cable is used, the data pins are connected but no power is provided to the KUSBA (v2.3).

Try using a different A to C cable with the data wires, while pressing the button. If it shows up as a drive, you can flash it again and use it with that cable. Since LAB4450 tests each KUSBA before shipping, I would expect it to work fine but if it doesn't work after testing a few USB cables it probably makes sense to contact them.

DK4FT, 2023-02-27:
Thanks for the recommendations - I close the issue here, as it seems to be HW related...

I tested different USB A to USB C cables, which I already used to sync phones or connected other devices.
As the KUSBA is nor shown on a Linux nor on a windows machine as a drive, i assume there is something wrong with the device and contact LAB4450.

I will followup with LAB4450...

DK4FT, 2023-02-28:
Lab4450 were very nice and assuming a bricked KUSBA device as well - they are sending a new one...

jperquin, 2023-03-01:
I have a similar issue, but AM able to copy compiled FW after connecting with reset button pressed:

```
sudo mount /dev/sda1 /mnt
sudo cp out/klipper.uf2 /mnt
sudo umount /mnt
```
Rebooting my main mcu or reconnecting the KUSBA does not help..

xbst, 2023-03-01:
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

You already have an issue open. Please don't post on other issues as it makes it difficult to keep track of it and offer help. Can you clarify the current problem in the issue you opened? Sounds like you now can flash the firmware to the KUSBA but not seeing the serial address?

jperquin, 2023-03-02:
Yeah sorry about that. I updated my klipper and was able to compile and upload the FW for the Rpi RP2040 to volume sda1, which makes me believe that the physical connection is OK.
So yes, you are right that I cannot see the serial address (eg. /dev/serial/by-id/usb-Klipper_rp2040_E6622C42E359A225-if00).

Your help is much appreciated.

jperquin, 2023-03-02:
One more reconnecting of the KUSBA appears to have solved the issue. :-)

```
pi@fluiddpi:~ $ ls /dev/serial/by-id/*
/dev/serial/by-id/usb-1a86_USB_Serial-if00-port0  /dev/serial/by-id/usb-Klipper_rp2040_E6622C42E359A225-if00
```

grahamr, 2023-08-10:
> Lab4450 were very nice and assuming a bricked KUSBA device as well - they are sending a new one...

Did the new one work? I found this older post trying to get mine working as well - tried 2 cords, a pi3b and a BTT CB1, and a windows box and macbook pro with no luck

DK4FT, 2023-08-10:
Yea, the new one worked like a charm.
The old kusba was simply doa by some unknown reason

Closed 2023-02-27.

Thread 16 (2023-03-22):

cannot get MCU address via  ls /dev/serial/by-id/*

marcosgeorgopoulos, 2023-03-22:
Hi,

I've just received from kusba and I am unable to to get the adxl mcu address.

I compiled the klipper.uf2 file as instructed.

I copied it across to the mount point, my distro auto mounted it

"/dev/sdb1 on /media/pi/RPI-RP2 type vfat (rw,nosuid,nodev,relatime,uid=1000,gid=1000,fmask=0022,dmask=0022,codepage=437,iocharset=ascii,shortname=mixed,showexec,utf8,flush,errors=remount-ro,uhelper=udisks2)"

but I tried mounting to /mnt as well and copied across the file, then unmounted.

I'm not sure if its expected but an ls on the device doesn't show the uf2 file, it does show any other file I copy across but and ls just shows

pi@printer:~ $ ls /media/pi/RPI-RP2/
INDEX.HTM  INFO_UF2.TXT

Here is the device being mounted from /var/messages

[ 2053.062303] sd 1:0:0:0: [sdb] Attached SCSI removable disk
[ 2170.531145] usb 1-1.1: USB disconnect, device number 11
[ 2173.366297] usb 1-1.1: new full-speed USB device number 12 using xhci_hcd
[ 2173.501450] usb 1-1.1: New USB device found, idVendor=2e8a, idProduct=0003, bcdDevice= 1.00
[ 2173.501479] usb 1-1.1: New USB device strings: Mfr=1, Product=2, SerialNumber=3
[ 2173.501500] usb 1-1.1: Product: RP2 Boot
[ 2173.501518] usb 1-1.1: Manufacturer: Raspberry Pi
[ 2173.501534] usb 1-1.1: SerialNumber: E0C9125B0D9B
[ 2173.508665] usb-storage 1-1.1:1.0: USB Mass Storage device detected
[ 2173.514383] scsi host1: usb-storage 1-1.1:1.0
[ 2174.559511] scsi 1:0:0:0: Direct-Access     RPI      RP2              3    PQ: 0 ANSI: 2
[ 2174.560261] sd 1:0:0:0: Attached scsi generic sg1 type 0
[ 2174.571427] sd 1:0:0:0: [sdb] 262144 512-byte logical blocks: (134 MB/128 MiB)
[ 2174.573559] sd 1:0:0:0: [sdb] Write Protect is off
[ 2174.573586] sd 1:0:0:0: [sdb] Mode Sense: 03 00 00 00
[ 2174.576013] sd 1:0:0:0: [sdb] No Caching mode page found
[ 2174.576037] sd 1:0:0:0: [sdb] Assuming drive cache: write through
[ 2174.588001]  sdb: sdb1
[ 2174.600077] sd 1:0:0:0: [sdb] Attached SCSI removable disk

Now my problem is I'm trying to get the adxl mcu address but ls /dev/serial/by-id/*  does not work.

Maybe I'm just doing something silly.  My RPI isn't currently plugged into my printer? Does it have to be? I didn't think so because I thought we are getting the MCU address of the KUSBA?

Thank you.

marcosgeorgopoulos, 2023-03-22:
ok... update, I'm silly... it seems I had to give the box a reboot and connect the device without holding the button for it to show up.

Closed 2023-03-22.

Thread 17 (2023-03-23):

Confused about orientation

bobg2023, 2023-03-23:
Hi,

I have a bed slinger ( Ender 3 ) I am about to setup my Kusba on.

I am going to use the mk6 nozzle mount for the hotend( X) axis and another mount for the bed (Y)

I have heard it said that you don’t have to worry about the orientation of how the Kusba is mounted because klipper just combines the values anyway, but from looking at the graphs produced  they are graphed separately and the m6 nozzle mount on this site says

‘ Add "axes_map: y, x, z" to [adxl345] section config for proper orientation with the USB-C facing forward.’

So I’m confused as to whether orientation matters when running SHAPER_CALIBRATE AXIS=X

Thank you

xbst, 2023-03-23:
It doesn't matter. That mount was contributed by another user, so that description was written by them, and I didn't edit it just in case someone wants to enter the "correct" axes map for that mount.
Klipper ignores the axes map for its calculations, like you said. The axes map only is used for visually marking each axis for the graphs generated by Klipper.

bobg2023, 2023-03-23:
Thank you for explaining.

Closed 2023-03-23.

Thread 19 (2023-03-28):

numpy issue

marcosgeorgopoulos, 2023-03-28:
Hi,

when trying to run a 'measure_axes_noise' like in the v2 video. I get the following error

!! Failed to import `numpy` module, make sure it was installed via `~/klippy-env/bin/pip install` (refer to docs/Measuring_Resonances.md for more details).

However I have installed numpy already as per the instructions. Installing it again confirms it install in the klippy-venv.

~/klippy-env/bin/pip install -v numpy
Using pip 23.0.1 from /home/pi/klippy-env/lib/python3.9/site-packages/pip (python 3.9)
Looking in indexes: https://pypi.org/simple, https://www.piwheels.org/simple
Requirement already satisfied: numpy in ./klippy-env/lib/python3.9/site-packages (1.24.2)

I just noticed its using python 3.9 as well. I install klipper via kiauh

marcosgeorgopoulos, 2023-03-28:
ok found the fix here.

https://numpy.org/devdocs/user/troubleshooting-importerror.html

I;m using a raspberry pi so had to do the following

sudo apt-get install libatlas-base-dev

see the link for more info,

Closed 2023-03-28.

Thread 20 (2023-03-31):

getting different recommended settings on Y axis

marcosgeorgopoulos, 2023-03-31:
Hi I have an ender 3 v2 and I'm using this mount for the bed

https://www.printables.com/model/296028-kusba-input-shaper-mount-for-ender-3-and-others

I 'clamps' to the bottom of the bed with a screw.

I find that I am getting different recommended shaper,freq and max_accel when I remount it in the same position ( the same as in the image on printable ) or on the right side.

I'm making sure the screw is as tight as possible.,

Is this expected?

thanks.

xbst, 2023-07-09:
I'm not sure how I missed this issue, sorry. LMK if you still need help.

Because you are clamping it on the bed manually, you likely aren't clamping it in the EXACT same position. The slight variation in mounting location can result in slightly different measurements, which can influence the recommended shaper and frequency. This is normal.

Closed 2023-07-09.

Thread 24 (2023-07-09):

KUsba not recognised

Reneeetje, 2023-07-09:
My raspberry pi 3 recognised the Kusba, my pi 4 does not, if i mount it and cp firmware, that is all ok on the pi 4, but afther reboot not recognised.

var/log
>
Jul  9 12:58:53 ender5plus mtp-probe: bus: 1, device: 5 was not an MTP device
Jul  9 13:06:23 ender5plus kernel: [  735.467182] usb 1-1.2: USB disconnect, device number 5
Jul  9 13:21:49 ender5plus kernel: [ 1661.520531] usb 1-1.2: new full-speed USB device number 6 using xhci_hcd
Jul  9 13:21:49 ender5plus kernel: [ 1661.632498] usb 1-1.2: New USB device found, idVendor=1d50, idProduct=614e, bcdDevice>
Jul  9 13:21:49 ender5plus kernel: [ 1661.632532] usb 1-1.2: New USB device strings: Mfr=1, Product=2, SerialNumber=0
Jul  9 13:21:49 ender5plus kernel: [ 1661.632547] usb 1-1.2: Product: Rampon
Jul  9 13:21:49 ender5plus kernel: [ 1661.632559] usb 1-1.2: Manufacturer: Anchor
Jul  9 13:21:49 ender5plus kernel: [ 1661.638559] cdc_acm 1-1.2:1.0: ttyACM0: USB ACM device
Jul  9 13:21:49 ender5plus mtp-probe: checking bus 1, device 6: "/sys/devices/platform/scb/fd500000.pcie/pci0000:00/0000:00>
Jul  9 13:21:49 ender5plus mtp-probe: bus: 1, device: 6 was not an MTP device
Jul  9 13:21:49 ender5plus mtp-probe: checking bus 1, device 6: "/sys/devices/platform/scb/fd500000.pcie/pci0000:00/0000:00>
Jul  9 13:21:49 ender5plus mtp-probe: bus: 1, device: 6 was not an MTP device
Jul  9 13:23:14 ender5plus mtp-probe: checking bus 1, device 4: "/sys/devices/platform/scb/fd500000.pcie/pci0000:00/0000:00>
Jul  9 13:23:14 ender5plus mtp-probe: bus: 1, device: 4 was not an MTP device
Jul  9 13:23:14 ender5plus mtp-probe: checking bus 1, device 3: "/sys/devices/platform/scb/fd500000.pcie/pci0000:00/0000:00>
Jul  9 13:23:14 ender5plus mtp-probe: bus: 1, device: 3 was not an MTP device

xbst, 2023-07-09:
So you only get this error on your pi 4 but not pi 3? If so it sounds like the problem is on your pi 4. I'm not really a Linux expert so I'm not sure if I can help with this.

Closed 2023-08-01.

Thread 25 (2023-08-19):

Kuba

pimp1310, 2023-08-19:

Alessiopell90, 2023-09-06:
Ciao, ho esattamente lo stesso problema tuo. Dopo vari tentativi oggi sono riuscito a fare l'input shaping però dal momento che spengo e riaccendo la stampante non mi trova più il seriale. Tu hai risolto?

Johnmkar, 2023-09-11:
I have the same problem. The KUSBA does not show up when I plug it in holding the boot button in. The ls /dev/ command results are identical with and without it plugged in. Unfortunately the KUBSA does not have any LED showing the unit is actually powered on so I can't even tell if it is working. I'm running Klipper on a BTT Pi v1.2 with a HDMI5 screen and I'm not sure if either one could be causing the issue.

Alessiopell90, 2023-09-11:
hi, I solved the problem. in the cfg printer I had the configuration of
another accelerometer and therefore they conflicted, after which I also
made a mistake in pressing the button when I wanted to make it work.
therefore, I insert the USB cable without pressing the button, I remove the
# from the cfg printer, I do shaper_calibrate, the first time it gives an
error and the second time it starts working.

Il Lun 11 Set 2023, 02:33 Johnmkar ***@***.***> ha scritto:

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

xbst, 2023-09-11:
I can't comment on the potential display conflict as I don't have a setup like that, but one of the first steps of troubleshooting issues like this is trying another USB cable. A lot of USB C cables don't have the data pins so it can't communicate with the Pi. I'd also try connecting it to a different computer to verify if the issue is caused by the setup with the display or cable or bad KUSBA. On a Windows PC, unflashed KUSBA will look like a USB drive, flashed one will open a serial (COM) port, which should show up in device manager.
________________________________
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

Alessiopell90, 2023-09-11:
I too have tried different cables, however I am noticing that every now and
then I connect the USB cable and there is no signal, I plug it in and out
2/3 times and it goes. it is a strange thing. Luckily it works but it's not
accurate on the first try

Il Lun 11 Set 2023, 16:58 xbst ***@***.***> ha scritto:

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

pellcorp, 2023-11-09:
So I can only get this to work if I copy the firmware over every time I plug it in.  So I need to hold the button down while plugging it in, then do these commands:

```
pi@klipper:~/klipper $ sudo mount /dev/sda1 /mnt
pi@klipper:~/klipper $ sudo cp out/klipper.uf2 /mnt
pi@klipper:~/klipper $ sudo umount /mnt
```

And the `ls /dev/serial/by-id/` shows the device, but if then unplug the device and then plug it in again, the device does not appear.

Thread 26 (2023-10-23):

Invalid adxl345 id (got ff vs e5)

DarkstarDev, 2023-10-23:
**The problem**: Running `ACCELEROMETER_QUERY` yields the following every time:
```
// Invalid adxl345 id (got ff vs e5).
// This is generally indicative of connection problems
// (e.g. faulty wiring) or a faulty adxl345 chip.
!! Invalid adxl345 id (got ff vs e5).
```

**What I've tried**:
* Verified communication with the printer
  * KUSBA device is listed in **/dev/serial/by-id/**
  * Disconnecting the KUSBA module crashes Klipper (`!! Lost communication with MCU 'adxl'`)
  * Restarting Klipper on the printer with KUSBA enabled in **printer.cfg**, but disconnected, continually crashes Klipper (`!! mcu 'adxl': Unable to connect`)
  * Commenting out the **include** line in **printer.cfg** and restarting Klipper on the printer restores normal functionality of the printer
  * Ensured I was following the [KUSBA v2 Instructions for Rampon](/xbst/KUSBA/blob/main/Docs/v2-Rampon-Firmware.md) (KUSBA came with Rampon installed)
* Successfully flashed Klipper onto KUSBA
* Followed [Kusba v2 Klipper Instructions](/xbst/KUSBA/blob/main/Docs/v2-Firmware.md) and edited **adxlmcu.cfg** according to the [Klipper config version](/xbst/KUSBA/blob/main/Firmware/v2/adxlmcu.cfg) (see latest version below)
* Updated **adxlmcu.cfg** to use software SPI, but received the error `adxl345: spi pins must be on same mcu`
* Tried multiple USB-C cables with the same results

**Additional information**
I tried running `ACCELEROMETER_QUERY` with KUSBA unplugged and disabled in configs. Received the same error (`Invalid adxl345 id (got ff vs e5).`). This seems to suggest that `ff` is the default state/response and I'm unable to get a successful response from the accelerometer. The fact that the USB device appears, can be flashed, and responds enough that Klipper doesn't crash when booting and communicating with the KUSBA seems to indicate a problem with the accelerometer on the KUSBA, but that's just my guess.

**Hardware**:
* Printer: Elegoo Neptune 4 Pro
* KUSBA: 2.4 (with Rampon, then Klipper)
* Cables: USB-A to USB-C
  * 6 inch cable
  * Multiple 6 foot cables from different brands

---
**~/klipper_config/printer.cfg**:
```
# This file contains common pin mappings for ELEGOO
# boards. To use this config, the firmware should be compiled for the
# stm32f407. When running "make menuconfig", select the 48KiB
# bootloader, and enable "Serial for communication" and select the "on USART1 PA10/PA9"
# See docs/Config_Reference.md for a description of parameters.

[include plr.cfg]
[include adxlmcu.cfg]
... more printer config here ...
```

**~/klipper_config/adxlmcu.cfg**:
```
[mcu adxl]
serial: /dev/serial/by-id/usb-Klipper_rp2040_E6624C90272F2721-if00
# Edit the above line with the correct serial address. Use "ls /dev/serial/by-id/*" to find the MCU serial address.

[adxl345]
cs_pin: adxl:gpio1

# Hardware SPI Option (Better results, "Invalid ID" Klipper bug with first query)
spi_bus: spi0a

# Software SPI Option (No "Invalid ID" Klipper bug with first query)
# spi_software_sclk_pin: adxl:gpio2
# spi_software_mosi_pin: adxl:gpio3
# spi_software_miso_pin: adxl:gpio0

[resonance_tester]
accel_chip: adxl345
probe_points:
   117,117,20
# Edit the above line with the correct probe points location. I recommend the center of your bed for X & Y, 20 for Z.
# For 350 mm printers: 175,175,20
# For 300 mm printers: 150,150,20
# For 250 mm printers: 125,125,20
# For 120 mm printers: 60,60,20

# More info: https://www.klipper3d.org/Config_Reference.html#adxl345
```

xbst, 2023-10-23:
Did you try Rampon before flashing Klipper? Rampon is the prefferred firmware because it is less buggy.

Can you flash Rampon again using the instructions here?:
https://github.com/xbst/KUSBA/blob/main/Docs/v2-Rampon-Firmware.md#1-flash-rampon-anchor-to-the-mcu
And use this adxlmcu.cfg:
https://github.com/xbst/KUSBA/blob/main/Firmware/v2-Rampon/adxlmcu.cfg

If this doesn't fix your issue, can you send your entire printer.cfg and other .cfgs included with [include]?

DarkstarDev, 2023-10-23:
While I did try initially following the instructions for Rampon, I did not try re-flashing Rampon, then configuring again. I can try that and see if anything changes.

DarkstarDev, 2023-10-23:
Unfortunately, the outcome appears to be the same after flashing and configuring. I verified the path to the USB device, and the printer boots fine with the device configured, but I still get `ff` as the response. As requested, here is my **printer.cfg** and the files it includes.

**printer.cfg**
```
# This file contains common pin mappings for ELEGOO
# boards. To use this config, the firmware should be compiled for the
# stm32f407. When running "make menuconfig", select the 48KiB
# bootloader, and enable "Serial for communication" and select the "on USART1 PA10/PA9"
# See docs/Config_Reference.md for a description of parameters.

[include plr.cfg]
[include adxlmcu.cfg]

[mcu]
# The hardware use USART1 PA10/PA9 connect to RK3328
serial: /dev/ttyS0
restart_method: command

[stepper_x]
step_pin:PC14
dir_pin:PC13
enable_pin:!PC15
microsteps: 16
rotation_distance: 40
full_steps_per_rotation:200  #set to 400 for 0.9 degree stepper
endstop_pin:PC0
position_min: -8
position_endstop:-8
position_max: 235
homing_speed:50
homing_retract_dist:5
homing_positive_dir:false
step_pulse_duration:0.000002

[stepper_y]
step_pin:PB4
dir_pin:PB3
enable_pin:!PB5
microsteps:16
rotation_distance: 40
full_steps_per_rotation:200  #set to 400 for 0.9 degree stepper
endstop_pin:PB8
position_min: 0
position_endstop:0
position_max:235
homing_speed:50
homing_retract_dist:5
homing_positive_dir:false
step_pulse_duration:0.000002

[stepper_z]
step_pin:PC10
dir_pin:!PA15
enable_pin: !PC11
microsteps: 16
rotation_distance: 8
full_steps_per_rotation: 200
endstop_pin:probe:z_virtual_endstop ## PB12 for Z-max; endstop have'!' is NO

##  Z-position of nozzle (in mm) to z-endstop trigger point relative to print surface (Z0)
##  (+) value = endstop above Z0, (-) value = endstop below
##	Increasing position_endstop brings nozzle closer to the bed
##  After you run Z_ENDSTOP_CALIBRATE, position_endstop will be stored at the very end of your config
#position_endstop:-5
position_max: 268
position_min: -5
homing_speed: 8
second_homing_speed: 3

[extruder]
step_pin:PA5
dir_pin:!PA6
enable_pin:!PA4
microsteps:16
rotation_distance: 31.4	#Bondtech 5mm Drive Gears
gear_ratio: 52:10
full_steps_per_rotation: 200	#200 for 1.8 degree, 400 for 0.9 degree
nozzle_diameter: 0.400
filament_diameter: 1.750
min_temp: 0
max_temp: 330
heater_pin: PA7
sensor_type:NTC 100K MGB18-104F39050L32
sensor_pin: PA1
max_power: 1
control :pid
pid_kp : 26.213
pid_ki : 1.304
pid_kd : 131.721
pressure_advance: 0.022
pressure_advance_smooth_time: 0.05
instantaneous_corner_velocity: 10.000
max_extrude_only_distance: 150
max_extrude_only_velocity:5000
max_extrude_only_accel:2000
step_pulse_duration:0.000002
max_extrude_cross_section: 50

[verify_heater extruder]
max_error: 120
check_gain_time:120
hysteresis: 10
heating_gain: 2

[heater_bed]
heater_pin:PB10
sensor_type: NTC 100K MGB18-104F39050L32
sensor_pin: PA0
max_power: 1.0
control = watermark
min_temp: 0
max_temp: 200

[verify_heater heater_bed]
max_error: 120
check_gain_time:120
hysteresis: 10
heating_gain: 1

#fan for printed model FAN0
[fan]
pin: PC9

#fan for hotend FAN1
[heater_fan fan1]
pin: PA8
shutdown_speed: 1

[printer]
kinematics:cartesian
max_velocity: 500
max_accel: 5000
max_accel_to_decel: 4000
max_z_velocity: 20
max_z_accel: 200
square_corner_velocity: 5.0

[input_shaper]
shaper_freq_x: 66.66
shaper_freq_y: 42.05
shaper_type_x: mzv
shaper_type_y: ei

####################################################################
#	Homing and Gantry Adjustment Routines
#####################################################################
[idle_timeout]
timeout: 36000

[safe_z_home]
home_xy_position: 141,98
speed: 100
z_hop: 10         
z_hop_speed: 5

[gcode_macro G29]
gcode:
      BED_MESH_CLEAR
      G28
      BED_MESH_CALIBRATE
      G0 X117 Y126 Z5 F3000
      G0 Z0 F300

#####################################################################
# 	Probe
#####################################################################

[probe]
pin:^PA11
x_offset: -24.25
y_offset: 20.45
z_offset: 0.0
speed: 10.0
samples: 2
samples_result: median
sample_retract_dist: 3.0
samples_tolerance: 0.1
samples_tolerance_retries: 1

[bed_mesh]
speed:120        
horizontal_move_z:10
mesh_min:10,21   
mesh_max:210,211 
probe_count:11,11  
algorithm:bicubic
bicubic_tension:0.2
mesh_pps: 4, 4
fade_start: 1.0
fade_end: 10.0

#####################################################################
# LED Control
#####################################################################
[output_pin caselight]
pin: PB7
pwm: false
shutdown_value:0
value:0.0

[output_pin caselight1]
pin: PC7
pwm: false
shutdown_value:0
value:0.0

[gcode_macro FLASHLIGHT_ON]
description: Turn on Hotend LEDs
gcode:
  SET_PIN PIN=caselight VALUE=1

[gcode_macro FLASHLIGHT_OFF]
description: Turn off Hotend LEDs
gcode:
  SET_PIN PIN=caselight VALUE=0

[gcode_macro MODLELIGHT_ON]
description: Turn on Logo LEDs
gcode:
  SET_PIN PIN=caselight1 VALUE=1

[gcode_macro MODLELIGHT_OFF]
description: Turn off Logo LEDs
gcode:
  SET_PIN PIN=caselight1 VALUE=0

[filament_switch_sensor fila]
pause_on_runout: True
runout_gcode:
            SET_FILAMENT_SENSOR SENSOR=fila ENABLE=1
event_delay: 3.0
pause_delay: 0.5
switch_pin: PA12

########################################
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
DarkstarDev, 2023-10-23:
I'm getting readings now. Thank you so much for your quick debugging on this. As a newbie to 3D printing, I didn't think to even check for conflicting configs since the Neptune 4 doesn't have a built-in accelerometer. I don't know what the best way to avoid this would be for future buyers, but a simple note in your documentation, or a troubleshooting guide might help.

Kudos for creating something that makes it so quick and easy to test, reflash, and reconfigure, and thank you again for your help.

Spedcat, 2024-11-13:
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

Hi im having some troubles with installing Rampon like you said becuase it seems like its refering to another accelerometer than I have (btt adxl345) and it references a file named "sda1" which is a file i dont have on my pi am I doing somthing wrong here?

Closed 2023-10-23.

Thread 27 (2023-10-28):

Kusba 2.4 instalation process

rastosk, 2023-10-28:
Hi i have received my kusba 2.4 from trianglelabs and i have to say what a beautiful work of art is this! When I was commissioning the accelerometer and following the guide:

  6.  Build the firmware

make

7.    Find the storage location of the KUSBA. This will usually be sda1. Use this command one time with the KUSBA unplugged and one time with KUSBA plugged in (while holding down the button on the KUSBA) to verify.

ls /dev/

   8. Flash the firmware.

sudo mount /dev/sda1 /mnt
sudo cp out/klipper.uf2 /mnt
sudo umount /mnt

Step 7 didn't make any sense to me so what i have done just skipped that step. Does this mean that my adxl will not work properly?
Thank you for your help!

Will-wastelander, 2023-10-28:
From the.looks, it's talking about the ls /dev/ command, so you can verify
the device ID is in fact sda1.

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

rastosk, 2023-10-28:
This what I have at L's /dev

serial: /dev/serial/by-id/usb-Klipper_rp2

Will-wastelander, 2023-10-28:
That would mean the device has already been flashed, and you will need to
hold the button while plugging in the USB cable to get to the bootloader.

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

rastosk, 2023-10-28:
Ok so just plug in hold the button and what do I look for?

Will-wastelander, 2023-10-28:
Exactly what you posted.

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

rastosk, 2023-10-28:
So when I hold button down it will boot differently? When I type Ls/dev what should come out?

xbst, 2023-10-31:
Just follow these instructions:

https://github.com/xbst/KUSBA/blob/main/Docs/v2-Rampon-Firmware.md#1-flash-rampon-anchor-to-the-mcu

You can flash the firmware on a Windows PC, it's easier.

rastosk, 2023-10-31:
I remember doing that with adxl345 board. But looks like this kusba come flashed ! Do they come flashed from factory? If so that must be very old firmware on it surprised that this actually works.

xbst, 2023-11-07:
There's no one "factory" for KUSBAs. I open sourced the files so there are many vendors, and each vendor orders from their preferred supplier. Some even make them themselves. Either way, they don't come with the firmware, it needs to be flashed. I flash all of mine before selling them. I know some other vendors do that too, but not all.
Rampon, unlike Klipper, doesn't need to be updated often. So if you bought from me or another vendor that pre-flashes rampon, it should be good to go. No update needed until there's a new rampon version.

pellcorp, 2023-11-09:
I actually had a problem getting mine to work, I have the 2.4 version

So I can only get this to work if I copy the firmware over every time I plug it in. So I need to hold the button down while plugging it in, then do these commands:

pi@klipper:~/klipper $ sudo mount /dev/sda1 /mnt
pi@klipper:~/klipper $ sudo cp out/klipper.uf2 /mnt
pi@klipper:~/klipper $ sudo umount /mnt

And the ls /dev/serial/by-id/ shows the device, but if then unplug the device and then plug it in again, the device does not appear.

Am I doing it wrong, or is the device defective.

This is the same issue for the Rampon as well

rastosk, 2023-11-09:
Hi pellcorp just follow this video and you will be golden. Supper easy
[https://www.youtube.com/watch?v=W_VHbT_tsZw](url)

pellcorp, 2023-11-09:
So it actually seems like have this exact issue https://github.com/xbst/KUSBA/issues/11

@rastosk I followed these steps to the letter, the issue is just like for issue #11, after I disconnect the device from the computer the flashed firmware gets reset, so it seems like I have a faulty board, I am chasing up a replacement from my vendor, fingers crossed they do the right thing.

rastosk, 2023-11-09:
That sucks man I gotine from aliexpress trianglelabs

pellcorp, 2023-11-09:
Seems like it just a random issue, and Unique Prints Shop  have already created a order to replace mine (they will now test that the one they send me saves the flash image correctly) and in the mean time I can use I just have to the mount cp, umount steps first.

sreknob, 2023-11-28:
I just received one from Triangle Labs that has the exact same issue, will work after flashing but won't show up as a serial device after a power cycle. I presume there is probably an issue with pulling the chip into run mode.

rastosk, 2023-11-28:
> I just received one from Triangle Labs that has the exact same issue, will work after flashing but won't show up as a serial device after a power cycle. I presume there is probably an issue with pulling the chip into run mode.

Interesting mine work fine after reboot. Try to reflash and follow steps thatbinposted above

sreknob, 2023-11-30:
> > I just received one from Triangle Labs that has the exact same issue, will work after flashing but won't show up as a serial device after a power cycle. I presume there is probably an issue with pulling the chip into run mode.
>
> Interesting mine work fine after reboot. Try to reflash and follow steps thatbinposted above

I have two from Triangle Labs, only one exhibits this behaviour. I have re-flashed several times, both from windows and linux with the same results. They came factory flashed with Rampon 0.2.0 and one didn't work immediately. Silkscreen says version 2.4. It was only after doing the reflash several times that I discovered this behaviour.

xbst, 2023-11-30:
I test all of my KUSBAs as this is a problem affecting a decent chunk of KUSBAs, depends on the batch but I see somewhere between 2-8% failure rate (usually closer to 2%). Here's a picture of all the KUSBAs I discarded and didn't sell in the past 6 months or so because of this issue:
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
Obviously discarding this many units is a big business expense, so they don't bother. And because of this and because I don't trust them to make it right when customers get a bad unit, I don't list them on the vendor list in this repo.

sreknob, 2023-12-01:
Fair enough! Next time I will order from you!

While trying to figure out what was going on, I had watched your video about the issues with the earlier revisions and the process to get to 2.3/2.4 so I guess I was just surprised that the flash erase issue was still a problem.

Thanks for all you do Isik!

xbst, 2023-12-02:
Yeah I thought the problem was fixed with v2.3 as all the units I ordered for the prototype run were working fine. I wasn't selling these back then so I didn't have a huge number of units to test.

Months later a few reports started coming from other vendors of 1-2% of units failing like that, and that is when I knew the issue wasn't fully fixed. I was still relying on other vendors reporting failed units to me at the time. When I started selling these about 6 months ago, I realized the fail percantage is actually 2-8%, depending on the batch. This high variability between batches is weird but I don't know what's going on exactly, just some theories. All I know for sure is, this only seems to happen on RP2040 based PCBs I design, which is part of the reason why I'm now using STM32s on newer projects.

Another observation is Rampon sometimes works fine on units that fail with Klipper. It's also less buggy on RP2040 (no failed first query bug), and doesn't require updates as often, and easier to use. So that's the firmware I recommend and the firmware I use to pre-flash/test my units.

rastosk, 2023-12-02:
The error that you get every time you do a query is same as Nero has in his video loose wire. The moment he puts wire in place and do query all is fixed . I'm wondering if the kusba issue could be related to that somehow. This is way beyond my knowledge just guessing here.

rastosk, 2023-12-02:
Oh cool how do I flash rampton? I don't mind the bug not a big deal but its a pain to reflash the klipper file after each upgrade

xbst, 2023-12-02:
https://github.com/xbst/KUSBA/blob/main/Docs/v2-Rampon-Firmware.md
________________________________
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

austwhite, 2024-02-29:
I just received a KUSBA from local reseller DREMC .   I have run into the issue of the firmware not sticking and erasing on a power cycle, like it is loaded into RAM but never makes it's way to flash or something.
Anyway, I wanted to ask here before I go back to DREMC to see if there was anyway to get the firmware to stick on one that has issues?     DREMC are usually fantastic and easy to talk to, I just want to make sure I exhaust all options before I go back to them

xbst, 2024-02-29:
> I just received a KUSBA from local reseller DREMC . I have run into the issue of the firmware not sticking and erasing on a power cycle, like it is loaded into RAM but never makes it's way to flash or something. Anyway, I wanted to ask here before I go back to DREMC to see if there was anyway to get the firmware to stick on one that has issues? DREMC are usually fantastic and easy to talk to, I just want to make sure I exhaust all options before I go back to them

Sometimes Rampon works fine on units that fail like that with Klipper, so if you're flashing Klipper, Rampon might help.

Other than this, not much can be done unfortunately. If it's bothering you, you need to contact DREMC for a replacement.

austwhite, 2024-02-29:
@xbst    More of a slight niggle than a bother.   Just means I have to flash it from the Linux CLI as if I dump the file from windows, of course it is gone when I disconnect it from the Windows machine.    I did try Rampon first to be honest.  No luck with my one :).
Thanks for the advice.   I appreciate it.

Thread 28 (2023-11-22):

KUSBA accelerator board orientation

tkocou, 2023-11-22:
I have a Flsun V400 which I would like to be able to use the accelerator board. I was wondering about what the proper orientation of the board would be. I can CAD a mounting board myself, but need to know how to orient the KUSBA board with respect to X,Y,Z axis. Would the 2 mounting holes be in alignment in the Z axis, or is there a different orientation?

xbst, 2023-11-22:
The ADXL345 axes are printed on the PCB, on the side with the components, above KUSBA.

That being said, for Klipper input shaping applications, you don't need to match the accelerometer axes to printer axes. Klipper uses the sum of the data from all 3 of the accelerometer axes when it's doing its input shaper calculations.

tkocou, 2023-11-22:
I looked. You are correct. The axis are printed. However, the type is very small. It is hard to see which direction each axis has. Thank you for the information.

Closed 2023-11-22.

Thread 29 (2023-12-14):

`Invalid adxl345 id (got 0 vs e5)`

Samywamy10, 2023-12-14:
Hi,
Recently got a Kusba from [Unique Prints in Australia](https://uniqueprints.shop/shop/electronics-electrical/pcb/kusba-usb-adxl345-accelerometer-for-klipper/) and I'm getting this `Invalid adxl345 id (got 0 vs e5)` error after using the Firmware v2 with Rampon.

I also tried non-Rampon and got the f2 error as described in other issues.

I've tried a whole bunch of different USB-C cables. In fact the one I'm using now I used to connect to the printer itself so its known working.

I can see the device is coming up in USB
```
sam@raspberrypi:~/adxl345spi $ lsusb
Bus 001 Device 005: ID 0451:8142 Texas Instruments, Inc. TUSB8041 4-Port Hub
Bus 001 Device 008: ID 1d50:614e OpenMoko, Inc. Rampon
Bus 001 Device 006: ID 1a86:7523 QinHeng Electronics CH340 serial converter
Bus 001 Device 002: ID 0451:8142 Texas Instruments, Inc. TUSB8041 4-Port Hub
Bus 001 Device 001: ID 1d6b:0002 Linux Foundation 2.0 root hub
sam@raspberrypi:~/adxl345spi $ ls /dev/serial/by-id/*
```

and as a device
```
sam@raspberrypi:~/adxl345spi $ ls /dev/serial/by-id/*
/dev/serial/by-id/usb-1a86_USB_Serial-if00-port0  /dev/serial/by-id/usb-Anchor_Rampon-if00
```

I tried using this [accelerometer reader ](https://github.com/nagimov/adxl345spi)and got all 0s as well (but i had the same output when I unplugged the device so not sure how accurate this is):

```
sam@raspberrypi:~/adxl345spi $ sudo ./adxl345spi
time = 0.000, x = 0.000, y = 0.000, z = 0.000
time = 0.200, x = 0.000, y = 0.000, z = 0.000
time = 0.400, x = 0.000, y = 0.000, z = 0.000
time = 0.601, x = 0.000, y = 0.000, z = 0.000
time = 0.801, x = 0.000, y = 0.000, z = 0.000
time = 1.001, x = 0.000, y = 0.000, z = 0.000
time = 1.201, x = 0.000, y = 0.000, z = 0.000
time = 1.401, x = 0.000, y = 0.000, z = 0.000
time = 1.601, x = 0.000, y = 0.000, z = 0.000
time = 1.802, x = 0.000, y = 0.000, z = 0.000
time = 2.002, x = 0.000, y = 0.000, z = 0.000
time = 2.202, x = 0.000, y = 0.000, z = 0.000
time = 2.402, x = 0.000, y = 0.000, z = 0.000
time = 2.602, x = 0.000, y = 0.000, z = 0.000
time = 2.803, x = 0.000, y = 0.000, z = 0.000
time = 3.003, x = 0.000, y = 0.000, z = 0.000
time = 3.203, x = 0.000, y = 0.000, z = 0.000
time = 3.403, x = 0.000, y = 0.000, z = 0.000
time = 3.603, x = 0.000, y = 0.000, z = 0.000
time = 3.803, x = 0.000, y = 0.000, z = 0.000
time = 4.004, x = 0.000, y = 0.000, z = 0.000
time = 4.204, x = 0.000, y = 0.000, z = 0.000
time = 4.404, x = 0.000, y = 0.000, z = 0.000
time = 4.604, x = 0.000, y = 0.000, z = 0.000
time = 4.804, x = 0.000, y = 0.000, z = 0.000
25 samples read in 5.04 seconds with sampling rate 5.0 Hz
Done
```

**adxlmcu.cfg**
```
[mcu adxl]
serial: /dev/serial/by-id/usb-Anchor_Rampon-if00

[adxl345]
cs_pin: adxl:CS

[resonance_tester]
accel_chip: adxl345
probe_points:
  110,110,20
# Edit the above line with the correct probe points location. I recommend the center of your bed for X & Y, 20 for Z.
# For 350 mm printers: 175,175,20
# For 300 mm printers: 150,150,20
# For 250 mm printers: 125,125,20
# For 120 mm printers: 60,60,20

# More info: https://www.klipper3d.org/Config_Reference.html#adxl345
```

Other configs:
<details><summary>Details</summary>
<p>

**printer.cfg**
```
# This file contains pin mappings for the stock 2022 Creality Ender 3
# V3 SE. To use this config, during "make menuconfig" select the
# STM32F103 with a "28KiB bootloader" and serial (on USART1 PA10/PA9)
# communication.

# If you prefer a direct serial connection, in "make menuconfig"
# select "Enable extra low-level configuration options" and select
# serial (on USART3 PB11/PB10), which is broken out on the 10 pin IDC
# cable used for the LCD module as follows:
# 3: Tx, 4: Rx, 9: GND, 10: VCC

# Flash this firmware by copying "out/klipper.bin" to a SD card and
# turning on the printer with the card inserted. The firmware
# filename must end in ".bin" and must not match the last filename
# that was flashed.

# This also works for the GD32F303 based Creality 4.2.2 board.

# See docs/Config_Reference.md for a description of parameters.

[include macro.cfg]
[include timelapse.cfg]
[exclude_object]
[include KAMP_Settings.cfg]

[include adxlmcu.cfg]

[respond]

[virtual_sdcard]
path: ~/printer_data/gcodes
on_error_gcode: CANCEL_PRINT

[stepper_x]
step_pin: PC2
dir_pin: !PB9
enable_pin: !PC3
microsteps: 16
rotation_distance: 40
endstop_pin: ~!PA5
position_endstop: -6
position_min: -6
position_max: 230
homing_speed: 80

[tmc2209 stepper_x]
uart_pin: PB12
run_current: 0.60
#hold_current: 0.5
sense_resistor: 0.150
#stealthchop_threshold: 999999
interpolate: True

[stepper_y]
step_pin: PB8
dir_pin: PB7
enable_pin: !PC3
microsteps: 16
rotation_distance: 40
endstop_pin: ~!PA6
position_endstop: -14
position_min: -14
position_max: 230
homing_speed: 80

[tmc2209 stepper_y]
uart_pin: PB13
run_current: 0.60
#hold_current: 0.5
sense_resistor: 0.150
#stealthchop_threshold: 999999
interpolate: True

[stepper_z]
step_pin: PB6
dir_pin: !PB5
enable_pin: !PC3
microsteps: 16
rotation_distance: 8
endstop_pin: probe:z_virtual_endstop
position_min: -3
position_max: 250
homing_speed: 4
second_homing_speed: 1
homing_retract_dist: 2.0

[tmc2209 stepper_z]
uart_pin: PB14
run_current: 0.8
#hold_current: 0.5
sense_resistor: 0.150
#stealthchop_threshold: 999999
interpolate: True

[extruder]
max_extrude_only_distance: 100.0
max_extrude_cross_section: 5
step_pin: PB4
dir_pin: PB3
enable_pin: !PC3
microsteps: 16
rotation_distance: 7.44
nozzle_diameter: 0.600
filament_diameter: 1.750
heater_pin: PA1
sensor_type: EPCOS 100K B57560G104F
sensor_pin: PC5
#control: pid
# tuned for stock hardware with 200 degree Celsius target
#pid_Kp: 27.142
#pid_Ki: 1.371
#pid_Kd: 134.351
min_temp: 0
max_temp: 260
pressure_advance = 0.08

[heater_bed]
heater_pin: PB2
sensor_type: EPCOS 100K B57560G104F
sensor_pin: PC4
#control: pid
# tuned for stock hardware with 70 degree Celsius target
#pid_kp: 66.371
#pid_ki: 0.846
#pid_kd: 1301.702
min_temp: 0
max_temp: 100

[heater_fan hotend_fan]
pin: PC1

[fan]
pin: PA0

[mcu]
serial: /dev/serial/by-id/usb-1a86_USB_Serial-if00-port0
restart_method: command

[printer]
kinematics: cartesian
max_velocity: 250
max_accel: 2500
max_z_velocity: 5
square_corner_velocity: 5.0
max_z_accel: 100

[bltouch]
sensor_pin: ^PC14
control_pin: PC13
x_offset: -26.0
y_offset: -17
z_offset: 1.63
#z_offset: 1.78
speed: 20
pin_move_time: 0.4
stow_on_each_sample: False
probe_with_touch_mode: True

[safe_z_home]
home_xy_position: 134,123
speed: 150
z_hop: 10
z_hop_speed: 10

[bed_mesh]
speed: 120
horizontal_move_z: 5
mesh_min: 30,30         # Need to handle head distance with cr-touch (bl_touch)
mesh_max: 204,213     # Max probe range (230-26,230-17)
probe_count: 5,5
algorithm: bicubic

[temperature_sensor mcu_temp]
sensor_type: temperature_mcu
min_temp: 0
max_temp: 100

[temperature_sensor Orange_Pi]
sensor_type: temperature_host
min_temp: 10
max_temp: 100

[pause_resume]
recover_velocity: 25

[display_status]

# [display]
# NOT IMPLEMTED (assuming it even works)

[output_pin beeper]
pin: PB0

[include prtouch.cfg]

#*# <---------------------- SAVE_CONFIG ---------------------->
#*# DO NOT EDIT THIS BLOCK OR BELOW. The contents are auto-generated.
#*#
#*# [heater_bed]
#*# control = pid
#*# pid_kp = 66.221
#*# pid_ki = 0.673
#*# pid_kd = 1629.031
#*#
#*# [extruder]
#*# control = pid
#*# pid_kp = 28.073
#*# pid_ki = 1.534
#*# pid_kd = 128.434
#*#
#*# [bed_mesh default]
#*# version = 1
#*# points =
#*# 	  0.352500, 0.340000, 0.252500, 0.202500, 0.142500
#*# 	  0.152500, 0.157500, 0.095000, 0.105000, 0.025000
#*# 	  -0.022500, -0.022500, -0.037500, -0.037500, -0.100000
#*# 	  -0.185000, -0.150000, -0.187500, -0.177500, -0.250000
#*# 	  -0.297500, -0.245000, -0.287500, -0.295000, -0.367500
#*# x_count = 5
#*# y_count = 5
#*# mesh_x_pps = 2
#*# mesh_y_pps = 2
#*# algo = bicubic
#*# tension = 0.2
#*# min_x = 30.0
#*# max_x = 204.0
#*# min_y = 30.0
#*# max_y = 213.0
#*#

```

**prtouch.cfg:**
```
[filter]

[dirzctl]
use_mcu: mcu

[hx711s]
use_mcu: mcu
count: 1
sensor0_clk_pin: PA4             # Pressure detection clock pin
sensor0_sdo_pin: PC6             # Pressure detection data pin

[prtouch]
sensor_x: 32
sensor_y: 30
clr_noz_start_x: 5
clr_noz_start_y: 20
clr_noz_len_x: 5
clr_noz_len_y: 25
bed_max_err: 5
show_msg: False
```

**macros.cfg:**
```
[gcode_macro START_PRINT]
gcode:
  {% set target_bed = params.BED|int %}
  {% set target_extruder = params.EXTRUDER|int %}
  {% set x_wait = printer.toolhead.axis_maximum.x|float / 2 %}
  {% set y_wait = printer.toolhead.axis_maximum.y|float / 2 %}
  # Use absolute coordinates
  G90
  M220 S100 ;Reset Feedrate
  M221 S100 ;Reset Flowrate

  M118 Homing
  G28 ;Home

  M118 Move to center
  G1 X{x_wait} Y{y_wait} Z15 F9000
  M118 Heat bed
  M190 S{target_bed}

  M118 Heat nozzle to 150c
  M109 S150 # Heats the nozzle to 150c for calibration

  # M118 Z offset
  # PRTOUCH_PROBE_ZOFFSET

  M118 KAMP calibrate
  BED_MESH_CALIBRATE

  M118 Smart park
  SMART_PARK

  M118 Heat mesh
  M109 S{target_extruder}

  M118 Purge
  LINE_PURGE

  M118 Reset extruder and get ready
  G92 E0  ;Reset Extruder
  G1 E-1.0000 F1800 ;Retract a bit
  G1 Z2.0 F3000 ;Move Z Axis up
  G1 E0.0000 F1800

[gcode_macro PID_EXTRUDER]
gcode:
  PID_CALIBRATE HEATER=extruder TARGET=210
  SAVE_CONFIG

[gcode_macro PID_BED]
gcode:
  PID_CALIBRATE HEATER=heater_bed TARGET=60
  SAVE_CONFIG

[gcode_macro FILAMENT_LOAD]
gcode:
    {% set load = params.L|default(100)|float * 0.5 %}
    {% set extruder_temp = params.T|default(210)|float %}
    SAVE_GCODE_STATE NAME=FILAMENT_LOAD_STATE
    LOW_TEMP_CHECK T={extruder_temp}
    M118 Loading filament
    M83                                                                         # relative extrusion
    G1 E{load} F1500                                                            # extrude fast
    G4 P1000                                                                    # wait 1 second
    G1 E{load} F200                                                             # extrude slow
    RESTORE_GCODE_STATE NAME=FILAMENT_LOAD_STATE
    BEEP

[gcode_macro FILAMENT_UNLOAD]
gcode:
    {% set unload = params.U|default(100)|float %}
    {% set extruder_temp = params.T|default(200)|float %}
    SAVE_GCODE_STATE NAME=FILAMENT_UNLOAD_STATE
    LOW_TEMP_CHECK T={extruder_temp}
    M118 Unloading filament
    M83                                                                         # relative extrusion
    G1 E2  F200                                                                 # extrude a little
    G1 E-10  F200                                                               # retract a little
    G1 E-{unload} F1500                                                         # retract a lot
    RESTORE_GCODE_STATE NAME=FILAMENT_UNLOAD_STATE

[gcode_macro LOW_TEMP_CHECK]
gcode:
    {% set extruder_temp = params.T|default(200)|float %}
    {% if printer.extruder.target > extruder_temp %}                            # if there is a setpoint for extruder
        {% set extruder_temp = printer.extruder.target %}
    {% endif %}
    {% if printer.extruder.temperature < extruder_temp %}                       # heat to the target
        M118 Heating to {extruder_temp}
        SET_HEATER_TEMPERATURE HEATER=extruder TARGET={extruder_temp}
        TEMPERATURE_WAIT SENSOR=extruder MINIMUM={extruder_temp}
    {% endif %}

[gcode_macro BEEP]
gcode:
    {% set duration = params.P|default(100)|float %}
    SET_PIN PIN=beeper VALUE=1
    G4 P{duration}
    SET_PIN PIN=beeper VALUE=0
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

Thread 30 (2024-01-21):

ADXL error after updating klipper

faxalex, 2024-01-21:
Hi, I'm Alessio..

premise that before the klipper update everything worked properly

MCU Protocol error This is frequently caused by running an older version of the firmware on the MCU(s). Fix by recompiling and flashing the firmware. Your Klipper version is: v0.12.0-85-gd785b396-dirty MCU(s) which should be updated: mcu: Current version v0.12.0-85-gd785b396 adxl: Current version v0.12.0-58-g25bc649c Up-to-date MCU(s): <none> Once the underlying issue is corrected, use the "RESTART" command to reload the config and restart the host software. mcu 'adxl': Command format mismatch: query_adxl345 oid=%c rest_ticks=%u vs query_adxl345 oid=%c clock=%u rest_ticks=%u

I tried updating the firmware with the latest version but nothing changed.
Could an update be necessary on your part or is it a klipper bug?

Thanks in advange

https://www.reddit.com/r/klippers/comments/19atuxh/adxl_error_after_updating_klipper/

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

xbst, 2024-01-21:
Apparently the latest Klipper update broke it. I'm not the dev of that firmware but I know they are already looking into it. You will need to reflash it with updated firmware when it gets released.

If you want to be able to use it in the meantime, Klipper firmware should still be working: https://github.com/xbst/KUSBA/blob/main/Docs/v2-Firmware.md

xbst, 2024-01-22:
New Rampon version supporting new Klipper:
https://github.com/rogerlz/rampon_anchor/blob/main/release/rampon_anchor_kusba.uf2

Closed 2024-01-22.

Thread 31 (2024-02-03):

Whenever I try to copy over the klipper.uf2 the KUSBA disconnects.

dvystrcil, 2024-02-03:
I have tried on my printer and my windows using WSL.

- I plug it in while holding the button, I can see the device.
- I can mount the folder as per the instructions.
- As soon as I copy the file over it device disappears.
- When I reattach the device I see that the file was not copied over.

I bought my KUSBA from Amazon from the [Isik's Tech Store](https://www.amazon.com/gp/product/B0C734JL4Z/ref=ppx_yo_dt_b_search_asin_title?ie=UTF8&psc=1)

What can I do to make this work properly?

dvystrcil, 2024-02-03:
I may have gotten this to work. Not sure what changed.

xbst, 2024-02-03:
The file won't show up again, but it'll be in the flash. You should see the serial port when the device isn't in flashing mode.

dvystrcil, 2024-02-03:
Thank you for following up with me. Yes, I understand that part now.

However when I unplug and plug the device back in without pressing the button. It does not show up again. I am forced to reflash and keep it plugged in. Is this expected?

Also is there a specific data cable I need to use? I have a shorter one (6 inches) which works, my longer one (6 feet) does not work with the device. Both of these cables work with my phone.

xbst, 2024-02-03:
Having to reflash after unplugging then pluging the cable back in is a known issue affecting a small percantage of KUSBAs, but KUSBAs I sell on Amazon are tested units without this issue when using Rampon firmware. Klipper is pickier than Rampon so if you're flashing Klipper instead of Rampon it might explain what you're experiencing. Rampon is also less buggy than Klipper, so that's the firmware I recommend, and the firmware I pre-flash. Instructions: https://github.com/xbst/KUSBA/blob/main/Docs/v2-Rampon-Firmware.md (Works with Klipper)

Since all units I sell on Amazon are tested with Rampon to not have this issue, I expect flashing Rampon to solve this issue. But if you still experience similar issues with Rampon, you should be able to return and/or request replacements on Amazon.

All USB C cables with data wires should work.

dvystrcil, 2024-02-03:
That worked. I also popped over to the discord to find clues on how to do x and y separately. I am printing now and have my fingers crossed.

Very shortly I will be updating Klipper, can I keep the existing input shaping or will I need to recalibrate it? I think I can just keep it since nothing about the physical printer is changing.

Thanks again for your help.

xbst, 2024-02-03:
You don't need to recalibrate after Klipper updates.

Closed 2024-02-03.

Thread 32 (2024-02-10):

Downloading adxlmcu.cfg file on Windows 11 messes up formatting

charminULTRA, 2024-02-10:
Within: https://github.com/xbst/KUSBA/blob/main/Docs/v2-Rampon-Firmware.md

"Download the [adxlmcu.cfg](https://github.com/xbst/KUSBA/blob/main/Firmware/v2-Rampon/adxlmcu.cfg) file from this repo and add it to your Klipper config directory."

I did this, and used the web interface on Mainsail to upload the file, without any editing, and the text wrapping was completely gone, and it's very hard to read. Instead I just copy pasted the real file contents. I'd recommend a warning in the instructions for PC users.

When I upload it into Mainsail, the file contents are, so something seems very wrong.

`{"payload":{"allShortcutsEnabled":true,"fileTree":{"Firmware/v2-Rampon":{"items":[{"name":"adxlmcu.cfg","path":"Firmware/v2-Rampon/adxlmcu.cfg","contentType":"file"}],"totalCount":1},"Firmware":{"items":[{"name":"v1","path":"Firmware/v1","contentType":"directory"},{"name":"v2-Rampon","path":"Firmware/v2-Rampon","contentType":"directory"},{"name":"v2","path":"Firmware/v2","contentType":"directory"}],"totalCount":3},"":{"items":[{"name":".github","path":".github","contentType":"directory"},{"name":"CAD","path":"CAD","contentType":"directory"},{"name":"Docs","path":"Docs","contentType":"directory"},{"name":"EasyEDA-Source","path":"EasyEDA-Source","contentType":"directory"},{"name":"Firmware","path":"Firmware","contentType":"directory"},{"name":"Gerbers","path":"Gerbers","contentType":"directory"},{"name":"Images","path":"Images","contentType":"directory"},{"name":"Mounts","path":"Mounts","contentType":"directory"},{"name":"LICENSE","path":"LICENSE","contentType":"file"},{"name":"README.md","path":"README.md","contentType":"file"}],"totalCount":10}},"fileTreeProcessingTime":4.750375,"foldersToFetch":[],"repo":{"id":478221104,"defaultBranch":"main","name":"KUSBA","ownerLogin":"xbst","currentUserCanPush":false,"isFork":false,"isEmpty":false,"createdAt":"2022-04-05T12:53:06.000-04:00","ownerAvatar":"https://avatars.githubusercontent.com/u/62180989?v=4","public":true,"private":false,"isOrgOwned":false},"symbolsExpanded":true,"treeExpanded":true,"refInfo":{"name":"main","listCacheKey":"v0:1686083309.607299","canEdit":true,"refType":"branch","currentOid":"1437d9c7ae85217e4cb4974874b8482226edf2ec"},"path":"Firmware/v2-Rampon/adxlmcu.cfg","currentUser":{"id":29433007,"login":"charminULTRA","userEmail":"jcw122@gmail.com"},"blob":{"rawLines":["[mcu adxl]","serial: /dev/serial/by-id/usb-Anchor_Rampon-if00","","[adxl345]","cs_pin: adxl:CS","","[resonance_tester]","accel_chip: adxl345","probe_points:","   0,0,0","# Edit the above line with the correct probe points location. I recommend the center of your bed for X & Y, 20 for Z.","# For 350 mm printers: 175,175,20","# For 300 mm printers: 150,150,20","# For 250 mm printers: 125,125,20","# For 120 mm printers: 60,60,20","","# More info: https://www.klipper3d.org/Config_Reference.html#adxl345"],"stylingDirectives":[[{"start":0,"end":10,"cssClass":"pl-en"}],[],[],[{"start":0,"end":9,"cssClass":"pl-en"}],[],[],[{"start":0,"end":18,"cssClass":"pl-en"}],[],[],[],[{"start":0,"end":117,"cssClass":"pl-c"},{"start":0,"end":1,"cssClass":"pl-c"}],[{"start":0,"end":33,"cssClass":"pl-c"},{"start":0,"end":1,"cssClass":"pl-c"}],[{"start":0,"end":33,"cssClass":"pl-c"},{"start":0,"end":1,"cssClass":"pl-c"}],[{"start":0,"end":33,"cssClass":"pl-c"},{"start":0,"end":1,"cssClass":"pl-c"}],[{"start":0,"end":31,"cssClass":"pl-c"},{"start":0,"end":1,"cssClass":"pl-c"}],[],[{"start":0,"end":68,"cssClass":"pl-c"},{"start":0,"end":1,"cssClass":"pl-c"}]],"csv":null,"csvError":null,"dependabotInfo":{"showConfigurationBanner":false,"configFilePath":null,"networkDependabotPath":"/xbst/KUSBA/network/updates","dismissConfigurationNoticePath":"/settings/dismiss-notice/dependabot_configuration_notice","configurationNoticeDismissed":false,"repoAlertsPath":"/xbst/KUSBA/security/dependabot","repoSecurityAndAnalysisPath":"/xbst/KUSBA/settings/security_analysis","repoOwnerIsOrg":false,"currentUserCanAdminRepo":false},"displayName":"adxlmcu.cfg","displayUrl":"https://github.com/xbst/KUSBA/blob/main/Firmware/v2-Rampon/adxlmcu.cfg?raw=true","headerInfo":{"blobSize":"472 Bytes","deleteInfo":{"deleteTooltip":"Fork this repository and delete the file"},"editInfo":{"editTooltip":"Fork this repository and edit the file"},"ghDesktopPath":"x-github-client://openRepo/https://github.com/xbst/KUSBA?branch=main&filepath=Firmware%2Fv2-Rampon%2Fadxlmcu.cfg","gitLfsPath":null,"onBranch":true,"shortPath":"183f14f","siteNavLoginPath":"/login?return_to=https%3A%2F%2Fgithub.com%2Fxbst%2FKUSBA%2Fblob%2Fmain%2FFirmware%2Fv2-Rampon%2Fadxlmcu.cfg","isCSV":false,"isRichtext":false,"toc":null,"lineInfo":{"truncatedLoc":"17","truncatedSloc":"14"},"mode":"file"},"image":false,"isCodeownersFile":null,"isPlain":false,"isValidLegacyIssueTemplate":false,"issueTemplateHelpUrl":"https://docs.github.com/articles/about-issue-and-pull-request-templates","issueTemplate":null,"discussionTemplate":null,"language":"INI","languageID":163,"large":false,"loggedIn":true,"newDiscussionPath":"/xbst/KUSBA/discussions/new","newIssuePath":"/xbst/KUSBA/issues/new","planSupportInfo":{"repoIsFork":null,"repoOwnedByCurrentUser":null,"requestFullPath":"/xbst/KUSBA/blob/main/Firmware/v2-Rampon/adxlmcu.cfg","showFreeOrgGatedFeatureMessage":null,"showPlanSupportBanner":null,"upgradeDataAttributes":null,"upgradePath":null},"publishBannersInfo":{"dismissActionNoticePath":"/settings/dismiss-notice/publish_action_from_dockerfile","releasePath":"/xbst/KUSBA/releases/new?marketplace=true","showPublishActionBanner":false},"rawBlobUrl":"https://github.com/xbst/KUSBA/raw/main/Firmware/v2-Rampon/adxlmcu.cfg","renderImageOrRaw":false,"richText":null,"renderedFileInfo":null,"shortPath":null,"symbolsEnabled":true,"tabSize":8,"topBannersInfo":{"overridingGlobalFundingFile":false,"globalPreferredFundingPath":null,"repoOwner":"xbst","repoName":"KUSBA","showInvalidCitationWarning":false,"citationHelpUrl":"https://docs.github.com/github/creating-cloning-and-archiving-repositories/creating-a-repository-on-github/about-citation-files","showDependabotConfigurationBanner":false,"actionsOnboardingTip":null},"truncated":false,"viewable":true,"workflowRedirectUrl":null,"symbols":{"timed_out":false,"not_analyzed":true,"symbols":[]}},"copilotInfo":null,"copilotAccessAllowed":false,"csrf_tokens":{"/xbst/KUSBA/branches":{"post":"AfkwcHjskUNBSYJ-77nCRbPRc3g_Qj3leOir6nac9FHi8Y7AcIAeL7VTGTjh9zBLSt0jN6zoBlIVuVHxHFUCWA"},"/repos/preferences":{"post":"wg8g0YKe21jTvDGIP2mks0hwvvyUAm392O7qaGnqy7_We9lngC3Ul8veuDlZDPG3P5EmzaOHY3E4SYYEQ5AcrQ"}}},"title":"KUSBA/Firmware/v2-Rampon/adxlmcu.cfg at main · xbst/KUSBA"}`

xbst, 2024-02-10:
I just downloaded this file and it downloaded just fine. Most people download this file on Windows and upload using Mainsail without any problems. Are you sure you didn't download page source or something like that instead of the raw file?

charminULTRA, 2024-02-10:
I right clicked the link and hit Save Link As, which is a typical action
for Windows to save things in their current format. Left clicking the link
brought me to the GitHub page of the file contents which isn’t what I
wanted or expected.

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

charminULTRA, 2024-02-10:
> I just downloaded this file and it downloaded just fine. Most people download this file on Windows and upload using Mainsail without any problems. Are you sure you didn't download page source or something like that instead of the raw file?

Following up here, when using the Download button on this page linked, it works fine: https://github.com/xbst/KUSBA/blob/main/Firmware/v2-Rampon/adxlmcu.cfg I can't explain why this doesn't work the same as Save Link As.

xbst, 2024-02-11:
It's because "save link as" saves the entire page, not just the file. So it includes everything you see when you click that link (GitHub logo, buttons, etc.) instead of just that file.

Closed 2024-02-11.

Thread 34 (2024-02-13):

M6 Mount Issue

charminULTRA, 2024-02-13:
https://github.com/xbst/KUSBA/blob/main/Mounts/M6_KUSBA_Mount.stl

The screw holes in the mount are larger than the screw holes in the KUSBA, therefore not mountable. The screws that fit the mount won't go through the KUSBA holes because they're too big.

xbst, 2024-02-13:
They're for M3 threaded inserts.

charminULTRA, 2024-02-13:
Oh ok, the instructions didn’t mention that.

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

Closed 2024-02-13.

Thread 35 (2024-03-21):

Is there a way to get the raw data directly using python

anass-al, 2024-03-21:
Hello  I have gotten access to some of your accelerometer and I'm interested in using then in a project that doesn't involve klipper.
Thank you

vgdh, 2024-03-21:
it would be pretty cool!

matmat07, 2024-08-05:
I know it's probably more efforts, but couldn't you use klipper's open source code to figure out how yourself? It's not the same language, but I wanted to suggest in case you didn't think of it.

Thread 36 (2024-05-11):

Installation problem

shkup, 2024-05-11:
I have Kusba v2.4. I followed the open issues here but I can't solve my issue. It seems the device port can't be connected to.
I already tried to flush it with the Rampon Anchor 0.4 to no avail.
In the `menuconfig` I selected "Raspberry PI RP2040" and as communication interface: "USBSERIAL".
Here are some outputs:
```
 dmesg | tail
[ 1091.945579] usb 1-1.4: Manufacturer: Anchor
[ 1091.950408] cdc_acm 1-1.4:1.0: ttyACM1: USB ACM device
[ 1212.095035] usb 1-1.5: USB disconnect, device number 6
[ 1212.400028] usb 1-1.5: new full-speed USB device number 13 using dwc_otg
[ 1212.534364] usb 1-1.5: New USB device found, idVendor=1d50, idProduct=614e, bcdDevice= 1.00
[ 1212.534389] usb 1-1.5: New USB device strings: Mfr=1, Product=2, SerialNumber=3
[ 1212.534397] usb 1-1.5: Product: rp2040
[ 1212.534403] usb 1-1.5: Manufacturer: Klipper
[ 1212.534409] usb 1-1.5: SerialNumber: 455035712894B258
[ 1212.535598] cdc_acm 1-1.5:1.0: ttyACM2: USB ACM device
```
For `lsusb` command:
```
 lsusb
Bus 001 Device 013: ID 1d50:614e OpenMoko, Inc. rp2040
Bus 001 Device 012: ID 1d50:614e OpenMoko, Inc. Rampon
Bus 001 Device 009: ID 1d50:614e OpenMoko, Inc. stm32f042x6
Bus 001 Device 003: ID 0424:ec00 Microchip Technology, Inc. (formerly SMSC) SMSC9512/9514 Fast Ethernet Adapter
Bus 001 Device 002: ID 0424:9514 Microchip Technology, Inc. (formerly SMSC) SMC9514 Hub
Bus 001 Device 001: ID 1d6b:0002 Linux Foundation 2.0 root hub
```
For `ls /dev/serial/by-id/` command:
```
usb-Anchor_Rampon-if00  usb-Klipper_rp2040_455035712894B258-if00  usb-Klipper_stm32f042x6_120001800743564E32313720-if00
```

From the command: ` sudo mount /dev/sda1 /mnt`
I get: `mount: /mnt: special device /dev/sda1 does not exist.`
I tried switching cables.
I also try to run a python code to attempt to read data from the device:
```
import serial
import time

# Set up serial connection (ensure the baud rate matches your device's configuration)
ser = serial.Serial('/dev/ttyACM2', 115200, timeout=1)

# Read from the device
try:
    while True:
        data = ser.readline()  # Read a line from the serial port
        if data:
            print(data.decode().strip())  # Print the data received from the device
        time.sleep(1)
except KeyboardInterrupt:
    print("Stopped by user")

# Close the serial connection
ser.close()
```
And get the error:
```
 File "/home/shkop/klipper/read_serial.py", line 10, in <module>
    data = ser.readline()  # Read a line from the serial port
  File "/usr/lib/python3/dist-packages/serial/serialposix.py", line 577, in read
    raise SerialException(
serial.serialutil.SerialException: device reports readiness to read but returned no data (device disconnected or multiple access on port?)
```
This is the config file:
```
[mcu adxl]
serial: /dev/serial/by-id/usb-Klipper_rp2040_455035712894B258-if00
# Edit the above line with the correct serial address. Use "ls /dev/serial/by-id/*" to find the MCU serial address.

[adxl345]
cs_pin: adxl:gpio1

# Hardware SPI Option (Better results, "Invalid ID" Klipper bug with first query)
spi_bus: spi0a

# Software SPI Option (No "Invalid ID" Klipper bug with first query)
# spi_software_sclk_pin: adxl:gpio2
# spi_software_mosi_pin: adxl:gpio3
# spi_software_miso_pin: adxl:gpio0

[resonance_tester]
accel_chip: adxl345
probe_points:
   60,60,20
# Edit the above line with the correct probe points location. I recommend the center of your bed for X & Y, 20 for Z.
# For 350 mm printers: 175,175,20
# For 300 mm printers: 150,150,20
# For 250 mm printers: 125,125,20
# For 120 mm printers: 60,60,20

# More info: https://www.klipper3d.org/Config_Reference.html#adxl345
```

Any idea what I can do to solve it?

shkup, 2024-05-12:
I think I sorted it out.
I think the firmware flashing routine is wrong.
On `klipper` documentation they suggest the following: (All the commands are `bash` ones you can run with `SSH` from `PuttY` except the `ACCELEROMETER_QUERY` that you un from `mainsail` console).

1. Download the `klipper` usb firmware [here](https://github.com/bigtreetech/SKR-Pico/blob/master/Klipper/klipper-USB.uf2)
2. Connect the `ADXL345` by a `usb` cable to the PC while pressing the boot button and copy the `u2f` file from stage 1, to the `ADXL345` device. (It will be identified as a storage device and open it as `RPI-RP2` folder).
3. While holding down the BOOT button on the device, connect it to the Raspberry Pi via USB.
4. Compile and flash the firmware in the device
```bash
make flash FLASH_DEVICE=first
```
If that fails, you will be told which FLASH_DEVICE to use. In this example, that's make flash FLASH_DEVICE=2e8a:0003.
After that you suppose to see the following output:
```
 Flashing out/klipper.uf2 to 2e8a:0003
sudo lib/rp2040_flash/rp2040_flash out/klipper.uf2

Loaded UF2 image with 109 pages
Found rp2040 device on USB bus 1 address 12
Flashing...
Resetting interface
Locking
Exiting XIP mode
Erasing
Flashing
Rebooting device
```
5. Now you can list the usb devices ids using `ls /dev/serial/by-id/*` command. If you have multiple entries and you are not sure who is the device: run `lsusb` command, disconnect the `ADXL345` usb, and run `lsusb` again. The missing id is your `ADXL345` device.
6. Make sure SPI is enabled in the raspberry pi. run the command: `sudo raspi-config`, Select Interfacing Options > SPI and enable it.
7. Copy the `ADXL345` board id from the `ls /dev/serial/by-id/*` command into your `adxl.cfg` serial id.
8. Restart `klipper` for good measure.
9. You should be able to send now `ACCELEROMETER_QUERY` commands in `mainsail` console.

Good Luck.

xbst, 2024-05-14:
I know the naming can be a bit confusing, but Rampon is fully compatible with Klipper firmware running on the printer's SBC (Pi, etc). Klipper firmware can be flashed to the KUSBA as well, but it is not recommended as it is buggier and more difficult to flash. However, for people who prefer to flash Klipper instead, the prefered method would be to build the firmware yourself because Klipper updates tend to break compatibility of previous versions. Linking a prebuilt firmware by BTT is not ideal because Klipper updates will likely break it soon.

The whole sda1 part can be worded better, I agree. What that part is about, is finding the KUSBA appearing as a USB drive so you can flash the firmware. Using `make flash FLASH_DEVICE=first` will likely result in people flashing the firmware they built for KUSBA to some other device. So, even though its more difficult, finding the correct sdx and flashing to that is preferable.

There is another way. Copying the Klipper.bin file to a computer, and just dragging and dropping it into the KUSBA, which will appear like a USB drive. This is how Rampon is flashed too. Much easier, quicker, less confusing. But the user needs to know how to copy the Klipper.bin file from the Pi to the computer, which a lot of users don't. So it's not a part of the Klipper instructions, only Rampon.

Most KUSBAs these days come with Rampon pre-flashed (looks like yours did as well) so there's no reason to do any of these. Just add the `adxlmcu.cfg` file, and should be ready to use. Enabling SPI on the Raspberry Pi (step 6) is also not necessary. We are not using the Pi's SPI bus (on its GPIO pins).

I understand the instructions are not perfect, and I appreciate the help, but in this case, this will only make the problem worse when a Klipper update breaks compatibility. I will try to come up with a better way of wording the sda1 part, and add further clarificarion about Klipper vs Rampon to avoid confusion.

shkup, 2024-05-14:
I agree but I couldn't flash the device as there was no SDA folder created no matter what I did.
I did try dropping the rampon firmware in the device using the PC method but still no SDA was present.
I don't know if I got a faulty USB device unit. The lack of status LEDs really makes it harder to diagnose.
I will try to flush the rampon firmware again.
Of course  it would be clearer if it would be explained that rampon firmware is compatible with Klipper.
Maybe you can add a troubleshooting section as it seems I'm not the only one struggling with it.

Thank you, Yaron.

Get Outlook for iOS<https://aka.ms/o0ukef>
________________________________
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

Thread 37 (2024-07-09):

KUSBA Unknown spi_bus 'spi0a'

CyberKK, 2024-07-09:
Hi,
I'm trying to set up my KUSBA with Klipper but I get the following error in Mainsail:

Klipper reports: ERROR

Unknown spi_bus 'spi0a'

I have followed the docs instructions but I can't get it to work. The KUSBA is showing when I SSH in with putty as /dev/serial/by-id/usb-Anchor_Rampon-if00 but it doesn't show up in Mainsail. The issue is with the KUSBA as if I comment out adxlmcu,cfg in the printer.cfg, then no issue occurs. I'm guessing I'm doing something wrong during install.

I've included the printer and adxl config files and the klipper and moonraker logs. I'd appreciate any help you can provide.

[klippy.log](https://github.com/user-attachments/files/16143916/klippy.log)
[moonraker.log](https://github.com/user-attachments/files/16143919/moonraker.log)

[printer.cfg.txt](https://github.com/user-attachments/files/16143882/printer.cfg.txt)
[adxlmcu.cfg.txt](https://github.com/user-attachments/files/16143884/adxlmcu.cfg.txt)

xbst, 2024-07-09:
You need to use this version of adxlmcu.cfg:
https://github.com/xbst/KUSBA/blob/main/Firmware/v2-Rampon/adxlmcu.cfg

CyberKK, 2024-07-09:
Thanks, that got it working.

Closed 2024-07-09.

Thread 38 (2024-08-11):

Setup following the the docs causes klipper not to start.

glennpierce, 2024-08-11:
Setup following the the docs causes klipper not to start.

I am sure this it me
but I bought a sensor that I believe has the latest firmware and followed the instructions at
https://github.com/xbst/KUSBA/blob/main/Docs/v2-Rampon-Firmware.md

I did a

ls /dev/serial/by-id/* to find the device and set it in the config

I can also do cat /dev/serial/by-id/usb-Seeed_XIAO_RP2040_E6611C0843441C34-if00 and it shows coordinates so i think the device is working fine and can communicate.

However, when I have [include adxlmcu.cfg] in the printer.cfg klipper fails to restart .

my log shows no errors I think. It is linked below.

https://pastebin.com/EVSP3Uta

Things seem to hang when it reaches

mcu 'adxl': Starting serial connect

What am i missing ?

My config seems ok

```
[mcu adxl]
serial = /dev/serial/by-id/usb-Seeed_XIAO_RP2040_E6611C0843441C34-if00

[adxl345]
cs_pin = adxl:CS

[resonance_tester]
accel_chip = adxl345
probe_points = 120,80,30
```

Thanks

Closed 2024-08-18.

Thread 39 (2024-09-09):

Invalid adxl345 id (got ff vs e5)

geekredux, 2024-09-09:
I'm having the same problem as an earlier user. My error message is slightly different though: `Invalid adxl345 id (got ff vs e5)`

I'm using Rampon v04 because my Klipper version is v0.12.0-289 (but I tried v03 also and got the same error).

I switched out USB cables with no success.

I'm also a little confused because all of the docs I've been reading have references to setting the SPI pins, but your `adxlmcu.cfg` file doesn't say anything about those. It only has the entry 'cs_pin: adxl:CS'. Are there supposed to be lines for `spi_software_sclk_pin`, `spi_software_mosi_pin`, and `spi_software_miso_pin` ?

I will add the printer does see the KUSBA board when it's plugged into the front. When I SSH in it does list as `/dev/serial/by-id/usb-Anchor_Rampon-if00` and it does throw an error when I unplug the cable. Also, it shows on Fluidd's System page (screengrab attached).

Ideas?

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

geekredux, 2024-09-09:
Oh, ffs... Never mind.

Okay, I was looking at only the open issues and didn't previously see closed issue #26. Your instructions in that issue to comment out these lines in printer.cfg solved the problem:

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

I will second @DarkstarDev's recommendation that you update the instructions at https://github.com/xbst/KUSBA/blob/main/Docs/v2-Rampon-Firmware.md to warn users they may need to do this with their printer.cfg file.

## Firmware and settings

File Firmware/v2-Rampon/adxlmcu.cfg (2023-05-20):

[mcu adxl]
serial: /dev/serial/by-id/usb-Anchor_Rampon-if00

[adxl345]
cs_pin: adxl:CS

[resonance_tester]
accel_chip: adxl345
probe_points:
   0,0,0
# Edit the above line with the correct probe points location. I recommend the center of your bed for X & Y, 20 for Z.
# For 350 mm printers: 175,175,20
# For 300 mm printers: 150,150,20
# For 250 mm printers: 125,125,20
# For 120 mm printers: 60,60,20

# More info: https://www.klipper3d.org/Config_Reference.html#adxl345

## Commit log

2022-04-05 Older Gerbers
    [BOM.csv, PNP.csv]
2022-05-26 adxlmcu.cfg for v1
    [adxlmcu.cfg]
2022-05-26 adxlmcu.cfg for v2
    [adxlmcu.cfg]
2022-05-29 Fixed a bug that affects a small percantage of PCBs
    [BOM.csv, PNP.csv]
2022-05-29 Actually fixed now
    [BOM.csv, PNP.csv]
2022-05-29 Really fixed now. Third time is the charm (for not being an idiot)
    [BOM.csv, PNP.csv]
2022-05-30 Working on fixing stuff
    [BOM.csv, PNP.csv]
2022-07-14 BOM fix
    [BOM.csv, PNP.csv]
2022-07-22 SB Cover by Samwiseg0
    [SB_cover.stl]
2022-07-24 miniab cover by samwiseg0
    [MiniAB_Cover.stl]
2022-08-04 CAD Files
    [Kusba-SB&MiniAB-Mounts.step]
2022-10-08 New AB mount (CAD later) and v2.4 (untested)
    [AfterBurner.stl, KUSBA_v2.4_BOM.csv, KUSBA_v2.4_PNP.csv]
2022-10-08 Reorganizing mounts folder
    [AfterBurner.stl, MiniAB.stl, MiniAB_Cover.stl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]
2023-01-08 v2.4 source
    [MiniAB.stl]
2023-01-08 MiniSB Mounts
    [Kusba-SB&MiniAB-Mounts.step, MiniSB_Front.stl, MiniSB_Patrick.stl]
2023-02-01 Adding M6 Nozzle Mount
    [M6_KUSBA_Mount.stl]
2023-02-02 Software SPI option added
    [adxlmcu.cfg]
2023-05-20 fix adxlmcu.cfg
    [adxlmcu.cfg]
2023-06-30 Added mount for MicroSwiss NG
    Tested with MicroSwiss NG Direct Drive extruder for Creality CR-10 and Ender 3 printers
    [MicroSwiss_NG.stl]
